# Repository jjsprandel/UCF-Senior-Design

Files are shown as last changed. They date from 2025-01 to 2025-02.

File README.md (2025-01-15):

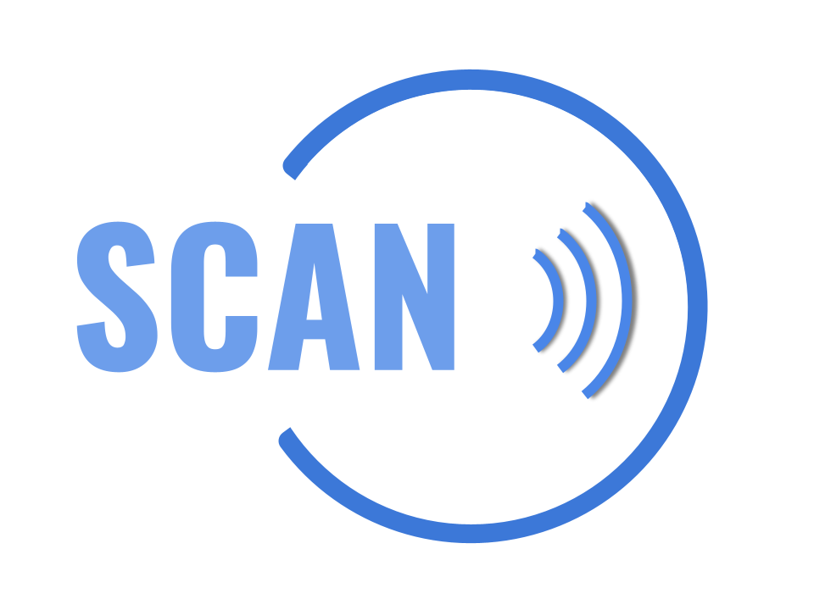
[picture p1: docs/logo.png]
Project Logo
# 

Welcome to the **SCAN** repository! Below, you will find all the necessary information, from hardware design to software documentation.

---

## GitHub Workflows Status 🔧

Here are the current statuses of our GitHub workflows:

| Workflow Name | Status |
| --- | --- |
| **CI - Build** |  |
| **Docker - Test Build** |  |

- **CI - Build**: Ensures the project builds successfully.
- **CI - Tests**: Runs all unit and integration tests to ensure everything is working as expected.
- **Docker - Test Build**: Attempts Docker Build upon changes to the Dockerfile.

---

## Table of Contents 📚
- [💡 Overview](#overview)
- [🔧 Hardware Design](#hardware-design)
- [💻 Software](#software)
- [🔨 Build Instructions](#build-instructions)
- [📑 Documentation](#documentation)
- [⚙️ License](#license)

---

## 💡 Overview
 **SCAN** is a low-cost, IoT-driven kiosk system designed to provide real-time analytics based on check-in and check-out information. By integrating NFC-based authentication, real-time data processing, and a user-friendly interface, SCAN provides users with a near-effortless check-in experience and provides facilities with actionable insights for improving operations. SCAN is able to track attendance and provide detailed analytics on occupancy trends, peak usage hours, and visit durations. These insights are accessible to administrator and facility managers via SCAN’s web application, which can provide them with the necessary statistics to allocate resources efficiently, optimize staffing, and improve user experiences.

---

## 🔧 Hardware Design
<details>
  <summary><strong>📡 Schematic</strong></summary>

  Below is the schematic of the hardware design:

  Schematic
  
  **Key Features**:
  - Feature 1
  - Feature 2
  - Feature 3

  Additional hardware files can be found in the [hardware directory](hardware_design).

</details>

<details>
  <summary><strong>🔌 PCB Design</strong></summary>

  Here's the PCB design layout:

  PCB

  **Important Notes**:
  - Note about the PCB.
  - Power considerations.
  - Any important design choices.

</details>

---

## 💻 Software
<details>
  <summary><strong>💾 Firmware Overview</strong></summary>

  The firmware is designed to work with the hardware for controlling the device. You can find the code [here](path/to/firmware).

  **Key Libraries Used**:
  - Library 1
  - Library 2

</details>

<details>
  <summary><strong>📦 Installation Guide</strong></summary>

  Follow these steps to install the firmware:
  
  1. Step 1
  2. Step 2
  3. Step 3

  Detailed instructions are available in the [installation guide](link_to_guide).

</details>

---

## 🔨 Build Instructions

<details>
  <summary><strong>🛠️ Build Setup</strong></summary>

  To build the project, follow these steps:

  1. Clone the repository:
     ```bash
     git clone https://github.com/jjsprandel/SCAN.git
     ```
  2. Connect your ESP32 to your computer using USB-C. The Docker container is designed to automatically recognize the device and use port 4000 to communicate to the ESP32 for flashing.
  3. Reopen Visual Studio Code in Container. This step requires having the Docker VS Code extension installed on your host machine. 
  4. Within the container, on first run, configure the ESP-IDF extension from the list of commands that come with the ESP-IDF extension.
     4a. Select "Use existing setup."
     4b. The extension should automatically find the right tool paths and folders. Select the configuration option with the auto-filled paths.
  5. Compile the firmware:
     ```bash
     idf.py build
     ```  
      5a. Alternatively, click the wrench button at the bottom of VS Code to build.
  6. Flash the firmware:
     ```bash
     idf.py --port 'rfc2217://host.docker.internal:4000?ign_set_control' flash
     ```
      6a. Alternatively, click the lightning button at the bottom of VS Code to flash.

  **Tips**:
  - Ensure your system meets the requirements listed in the [build prerequisites](link_to_prerequisites).
  - If you encounter issues, check the [troubleshooting guide](link_to_troubleshooting).

</details>

---

## 📑 Documentation
<details>
  <summary><strong>📝 API Documentation</strong></summary>

  - **[API Reference](link_to_api_reference)**: Detailed API usage and function descriptions.
  - **[Hardware Docs](link_to_hardware_docs)**: Documentation on hardware design.

</details>

<details>
  <summary><strong>📚 Additional Resources</strong></summary>

  - **[Project Wiki](link_to_wiki)**: Explore the project wiki for more in-depth articles.
  - **[User Manual](link_to_user_manual)**: Comprehensive user guide for operation.

</details>

---

## 🔌 Dependencies

This project has the following dependencies that need to be installed:

### **Hardware Dependencies:**
- **KiCad Version**: 8.0.6 (required for schematic and PCB design)
  - Download from [KiCad official website](https://kicad.org/download/).
  
### **Software Dependencies:**
- **USB Drivers**: For proper communication with the hardware, ensure that the appropriate USB drivers are installed.
  - For Windows, you can download and install the **[CP210x USB to UART Bridge VCP drivers](https://www.silabs.com/developer-tools/usb-to-uart-bridge-vcp-drivers?tab=downloads)**.
  - For Linux, you should have the necessary drivers already built into the kernel, but check the [driver documentation](https://www.silabs.com/community/interface/usb-bridges) for troubleshooting.

- **Docker Desktop**: Required to run the ESP-IDF containerized environment.
  - Download from **[Docker Desktop website](https://www.docker.com/products/docker-desktop)**.
  - Follow the installation instructions for your operating system.
  
### **Development Tools:**
- **[Visual Studio Code](https://code.visualstudio.com/)**: Recommended IDE for editing the firmware code.

- **[Git](https://git-scm.com/)**: Version control system.

---

## ⚙️ License
SCAN © 2025 is licensed under Creative Commons Attribution-NonCommercial-NoDerivatives 4.0 International. To view a copy of this license, visit https://creativecommons.org/licenses/by-nc-nd/4.0/ or see the [LICENSE](LICENSE) file.

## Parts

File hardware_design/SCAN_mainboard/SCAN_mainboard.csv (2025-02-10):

Reference | Value | Datasheet | Footprint | Qty | DNP
BZ1 | Buzzer | ~ | Connector_PinHeader_2.54mm:PinHeader_1x02_P2.54mm_Vertical | 1
C1,C9,C10,C24,C25,C26,C27,C28,C29,C30,C31,C32,C35,C53,C54,C55,C63,C65 | 10u | ~ | -- mixed values -- | 18
C2,C11,C12,C15,C21,C22,C44,C45,C59 | 0.1u | ~ | -- mixed values -- | 9
C3,C43,C46,C50,C51,C52,C58 | 1u | ~ | -- mixed values -- | 7
C4 | 0.1uF | ~ |  | 1
C5,C6 | 1u | ~ | Capacitor_SMD:C_0805_2012Metric | 2 | DNP
C8,C33,C34,C36,C37 | 10u | ~ | -- mixed values -- | 5 | DNP
C13,C14 | 1nF | ~ | Capacitor_SMD:C_0402_1005Metric | 2
C16,C17 | 0.01u | ~ | Capacitor_SMD:C_0402_1005Metric | 2 | DNP
C18 | 4.7u | ~ | Capacitor_SMD:C_0603_1608Metric | 1
C19 | 47n | ~ | Capacitor_SMD:C_0402_1005Metric | 1
C20,C41 | 47nF | ~ | Capacitor_SMD:C_0402_1005Metric | 2
C23 | 0.1u | ~ | Capacitor_SMD:C_0402_1005Metric | 1 | DNP
C38,C40 | 33u | ~ | Capacitor_Tantalum_SMD:CP_EIA-7343-31_Kemet-D | 2
C39 | 33u | ~ | Capacitor_Tantalum_SMD:CP_EIA-7343-31_Kemet-D | 1 | DNP
C42 | ~ | ~ |  | 1 | DNP
C47,C48 | 390p | ~ | Capacitor_SMD:C_0603_1608Metric | 2
C49 | 3.3u | ~ | Capacitor_SMD:C_1210_3225Metric | 1
C56,C57,C60,C61 | 0.47u | ~ | Capacitor_SMD:C_0603_1608Metric | 4
C62,C64,C66 | 47u | ~ | Capacitor_SMD:C_1210_3225Metric | 3
C67 | 10p | ~ | Capacitor_SMD:C_0603_1608Metric | 1
C68 | 100n | ~ | Capacitor_SMD:C_0402_1005Metric | 1
D1,D2,D3,D4 | ESD441 |  | SCAN_footprints:X2SON2_DPL_TEX | 4
D5,D6,D7 | WS2812B | https://cdn-shop.adafruit.com/datasheets/WS2812B.pdf | LED_SMD:LED_WS2812B_PLCC4_5.0x5.0mm_P3.2mm | 3
D8,D14 | 1N4148W | https://www.vishay.com/docs/85748/1n4148w.pdf | Diode_SMD:D_SOD-123 | 2
D11,D12 | 12V | ~ | Diode_SMD:D_SOD-523 | 2
D13 | LED | ~ | LED_SMD:LED_0805_2012Metric | 1
D15 | NZH10C-115 | https://assets.nexperia.com/documents/data-sheet/NZH_SER.pdf | SCAN_footprints:SODFL3516X120N | 1
D16 | RED | ~ | LED_SMD:LED_0603_1608Metric | 1
J1 | USB_C_16P_Connector | https://www.usb.org/sites/default/files/documents/usb_type-c.zip | SCAN_footprints:USB4110-GF-A_GCT | 1
J2 | Batt_Connector | ~ | SCAN_footprints:TE_282856-2 | 1
J3 | PV_Panel_Connector | ~ | SCAN_footprints:TE_282856-2 | 1
J4 | PIR_CONNECTOR | ~ | Connector_PinHeader_2.54mm:PinHeader_1x03_P2.54mm_Vertical | 1
J5 | Debug_Breakout | ~ |  | 1
J6 | Power_Breakout | ~ |  | 1
J7 | Conn_01x08 | ~ | Connector_PinHeader_2.54mm:PinHeader_1x08_P2.54mm_Vertical | 1
J8 | Conn_01x12 | ~ | SCAN_footprints:12-pin-0.7mm-FPC-Pad | 1
J9 | Keypad | ~ |  | 1
L1 | 1.0u | ~ | SCAN_footprints:SPM6530 | 1
L2 | 2.2u | ~ | SCAN_footprints:IND_IHLP-3232DZ_VIS | 1
Q2,Q3,Q4,Q5 | CSD17581Q3A | https://www.ti.com/lit/ds/symlink/csd17581q3a.pdf | Package_SON:VSON-8_3.3x3.3mm_P0.65mm_NexFET | 4
Q6 | CSD17575Q3 | https://www.ti.com/lit/ds/symlink/csd17577q3a.pdf | Package_SON:VSON-8_3.3x3.3mm_P0.65mm_NexFET | 1
Q7 | BC847BDW1 | http://www.onsemi.com/pub_link/Collateral/BC846BDW1T1-D.PDF | Package_TO_SOT_SMD:SOT-363_SC-70-6 | 1
Q8 | IRF9358TRPBF | https://www.diodes.com//assets/Datasheets/ds31420.pdf | SCAN_footprints:SO8_IRF9358TRPBF_INF | 1
Q9 | BSL308PE | BSL308PEH6327XTSA1 | SCAN_footprints:PG-TSOP6-6-4_INF | 1
Q10 | NTR4503NT1G |  | SCAN_footprints:SOT23_318-08_ONS | 1
R1,R2,R27 | 2.2k | ~ | -- mixed values -- | 3
R3,R4,R5,R10,R14,R17,R34,R37,R49 | 10k | ~ | -- mixed values -- | 9
R15,R16,R29,R30,R31,R67 | 0.01 | ~ | Resistor_SMD:R_2010_5025Metric | 6
R18,R19 | 100k | ~ | Resistor_SMD:R_0402_1005Metric | 2 | DNP
R20,R21,R56 | 0 | ~ | Resistor_SMD:R_0805_2012Metric | 3 | DNP
R22 | 127k | ~ | Resistor_SMD:R_0603_1608Metric | 1
R23,R57,R63,R64 | 100k | ~ | -- mixed values -- | 4
R24,R25 | 294 | ~ | Resistor_SMD:R_0603_1608Metric | 2
R26 | 6.04k | ~ | Resistor_SMD:R_0603_1608Metric | 1
R28 | 100 | ~ | Resistor_SMD:R_0603_1608Metric | 1
R32 | 5.24k | ~ | Resistor_SMD:R_0402_1005Metric | 1
R33 | 30.1k | ~ | Resistor_SMD:R_0402_1005Metric | 1
R35 | 3.3k | ~ |  | 1
R36,R38,R39,R61,R62 | 0Ω | ~ | -- mixed values -- | 5
R40,R52 | 49.9k | ~ | Resistor_SMD:R_0402_1005Metric | 2
R41,R43,R47 | DNP | ~ | Resistor_SMD:R_0603_1608Metric | 3 | DNP
R42,R44,R48,R51,R53,R58,R59 | 1k | ~ | -- mixed values -- | 7
R45,R46 | 5.1k | ~ | Resistor_SMD:R_0603_1608Metric | 2
R50 | 0 | ~ | Resistor_SMD:R_0402_1005Metric | 1
R54,R55 | 2k | ~ | Resistor_SMD:R_0402_1005Metric | 2
R60 | 0Ω | ~ | Resistor_SMD:R_0805_2012Metric | 1 | DNP
R65 | 43.2k | ~ | Resistor_SMD:R_0603_1608Metric | 1
R66 | 4.99k | ~ | Resistor_SMD:R_0603_1608Metric | 1
TH1 | Thermistor_NTC | ~ | Resistor_THT:R_Radial_Power_L11.0mm_W7.0mm_P5.00mm | 1
TP1,TP2,TP3,TP4,TP6,TP7,TP8,TP9,TP10,TP11,TP12,TP13,TP14,TP15,TP16,TP18,TP19,TP20 | TestPoint | ~ | TestPoint:TestPoint_Pad_2.0x2.0mm | 18
U1 | ESP32-C6-WROOM-1-N8 | https://www.espressif.com/sites/default/files/documentation/esp32-c6-wroom-1_wroom-1u_datasheet_en.pdf | SCAN_footprints:ESP32-C6-WROOM-1-N8 | 1
U2 | PCF8574 | http://www.nxp.com/docs/en/data-sheet/PCF8574_PCF8574A.pdf |  | 1
U4 | BQ25798RQMR | BQ25798RQMR | SCAN_footprints:IC_BQ25798RQMR | 1
U5 | TVS2200DRV | http://www.ti.com/lit/ds/symlink/tvs2200.pdf | Package_SON:WSON-6-1EP_2x2mm_P0.65mm_EP1x1.6mm | 1
U6 | CYPD3177-24LQXQ | https://au.mouser.com/datasheet/2/196/CYPR_S_A0012903526_1-3004964.pdf | SCAN_footprints:QFN50P400X400X60-25N-D | 1
U7 | ESD122 | ESD122DMYR | SCAN_footprints:DMY0003A | 1
U8 | CP2102N-A02-xQFN28 | https://www.silabs.com/documents/public/data-sheets/cp2102n-datasheet.pdf | Package_DFN_QFN:QFN-28-1EP_5x5mm_P0.5mm_EP3.35x3.35mm | 1
U9 | LM62460Q3RPHRQ1 |  | SCAN_footprints:16-VQFN-HR | 1

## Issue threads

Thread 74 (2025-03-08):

NFC problem reading tag with fast movement

jjsprandel, 2025-03-08:
When a user quickly moves their NFC tag into range of the PN532 reader, the software cannot read the data. The current code requires the tag to be moved into range slowly, posing an issue for typical interactions with the kiosk

Closed 2025-04-12.

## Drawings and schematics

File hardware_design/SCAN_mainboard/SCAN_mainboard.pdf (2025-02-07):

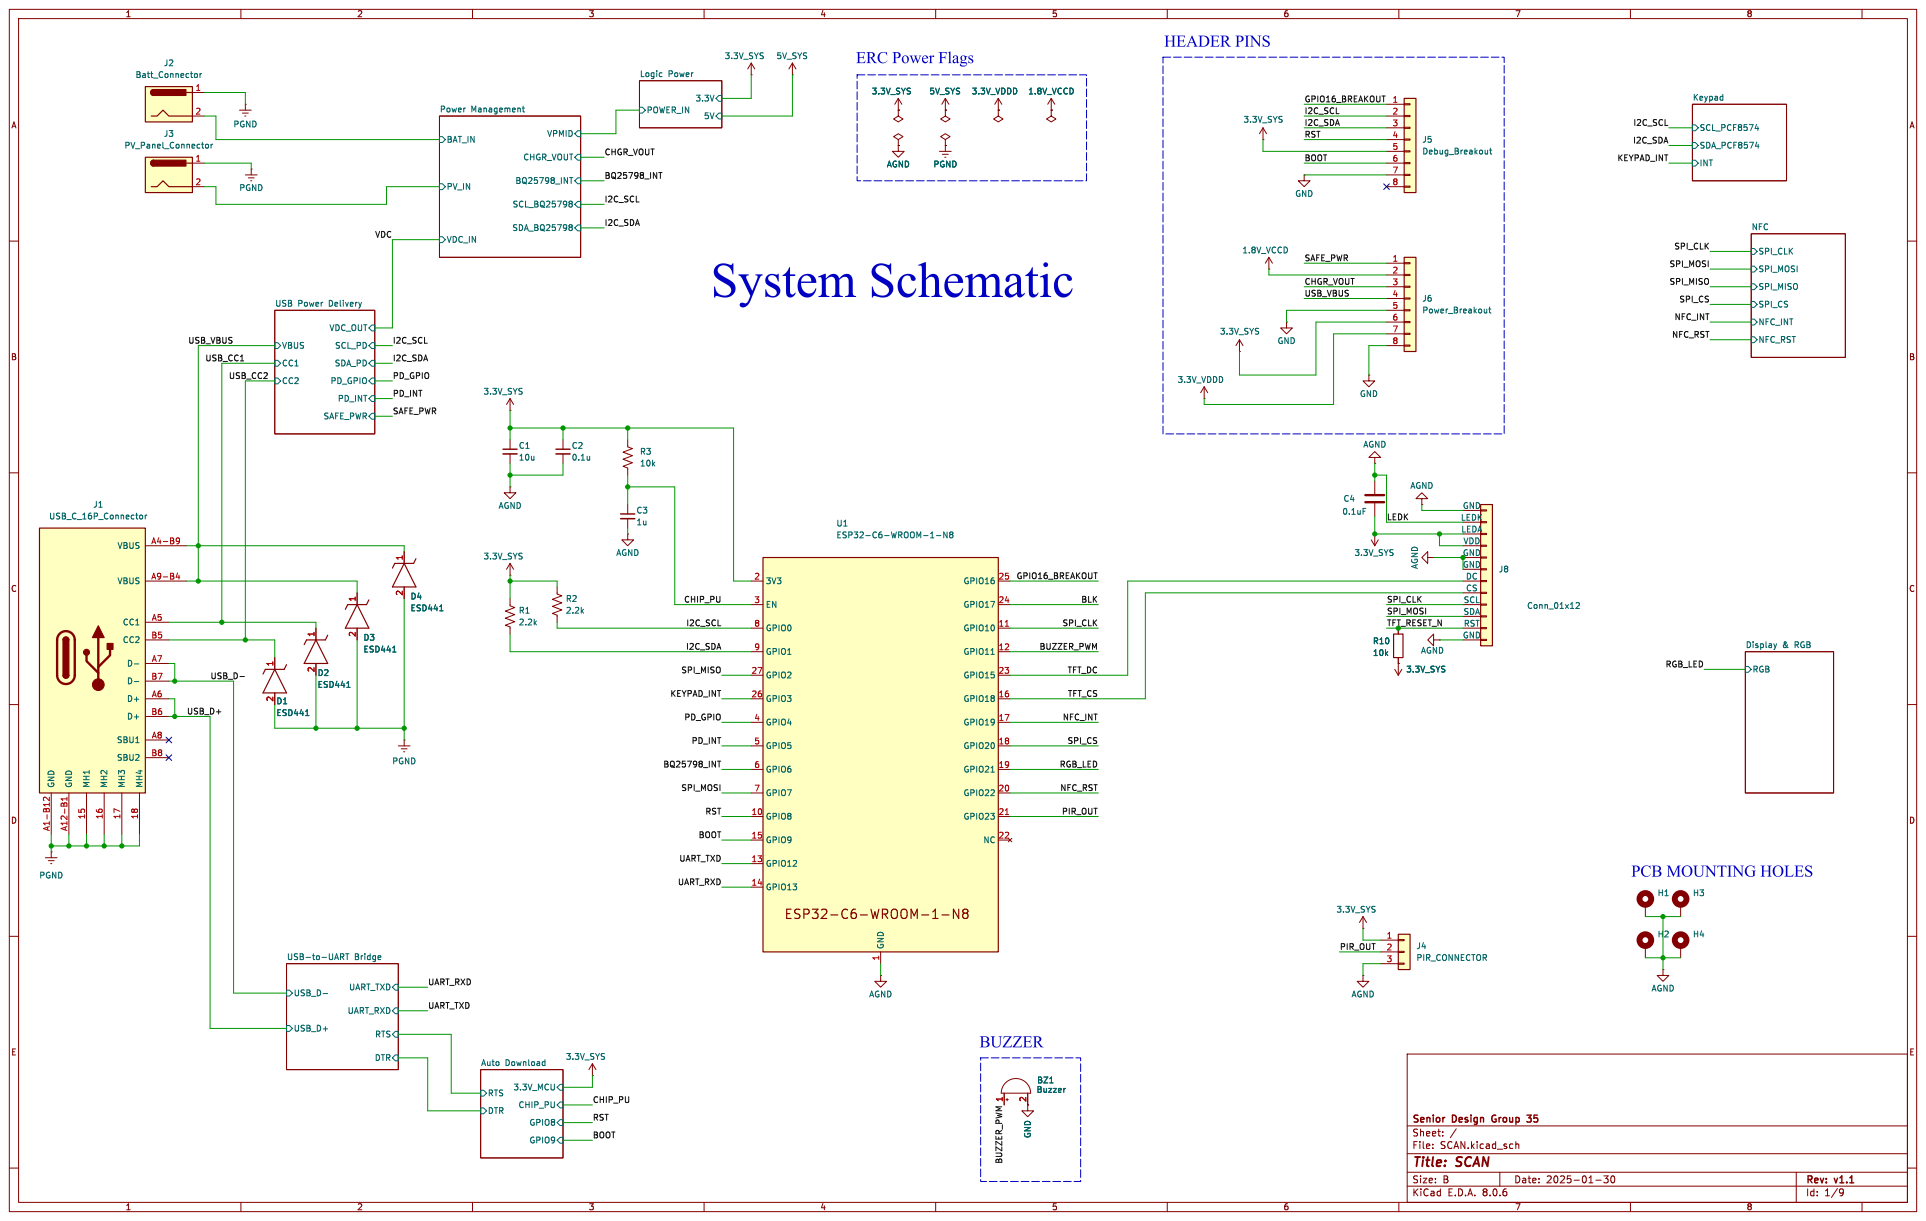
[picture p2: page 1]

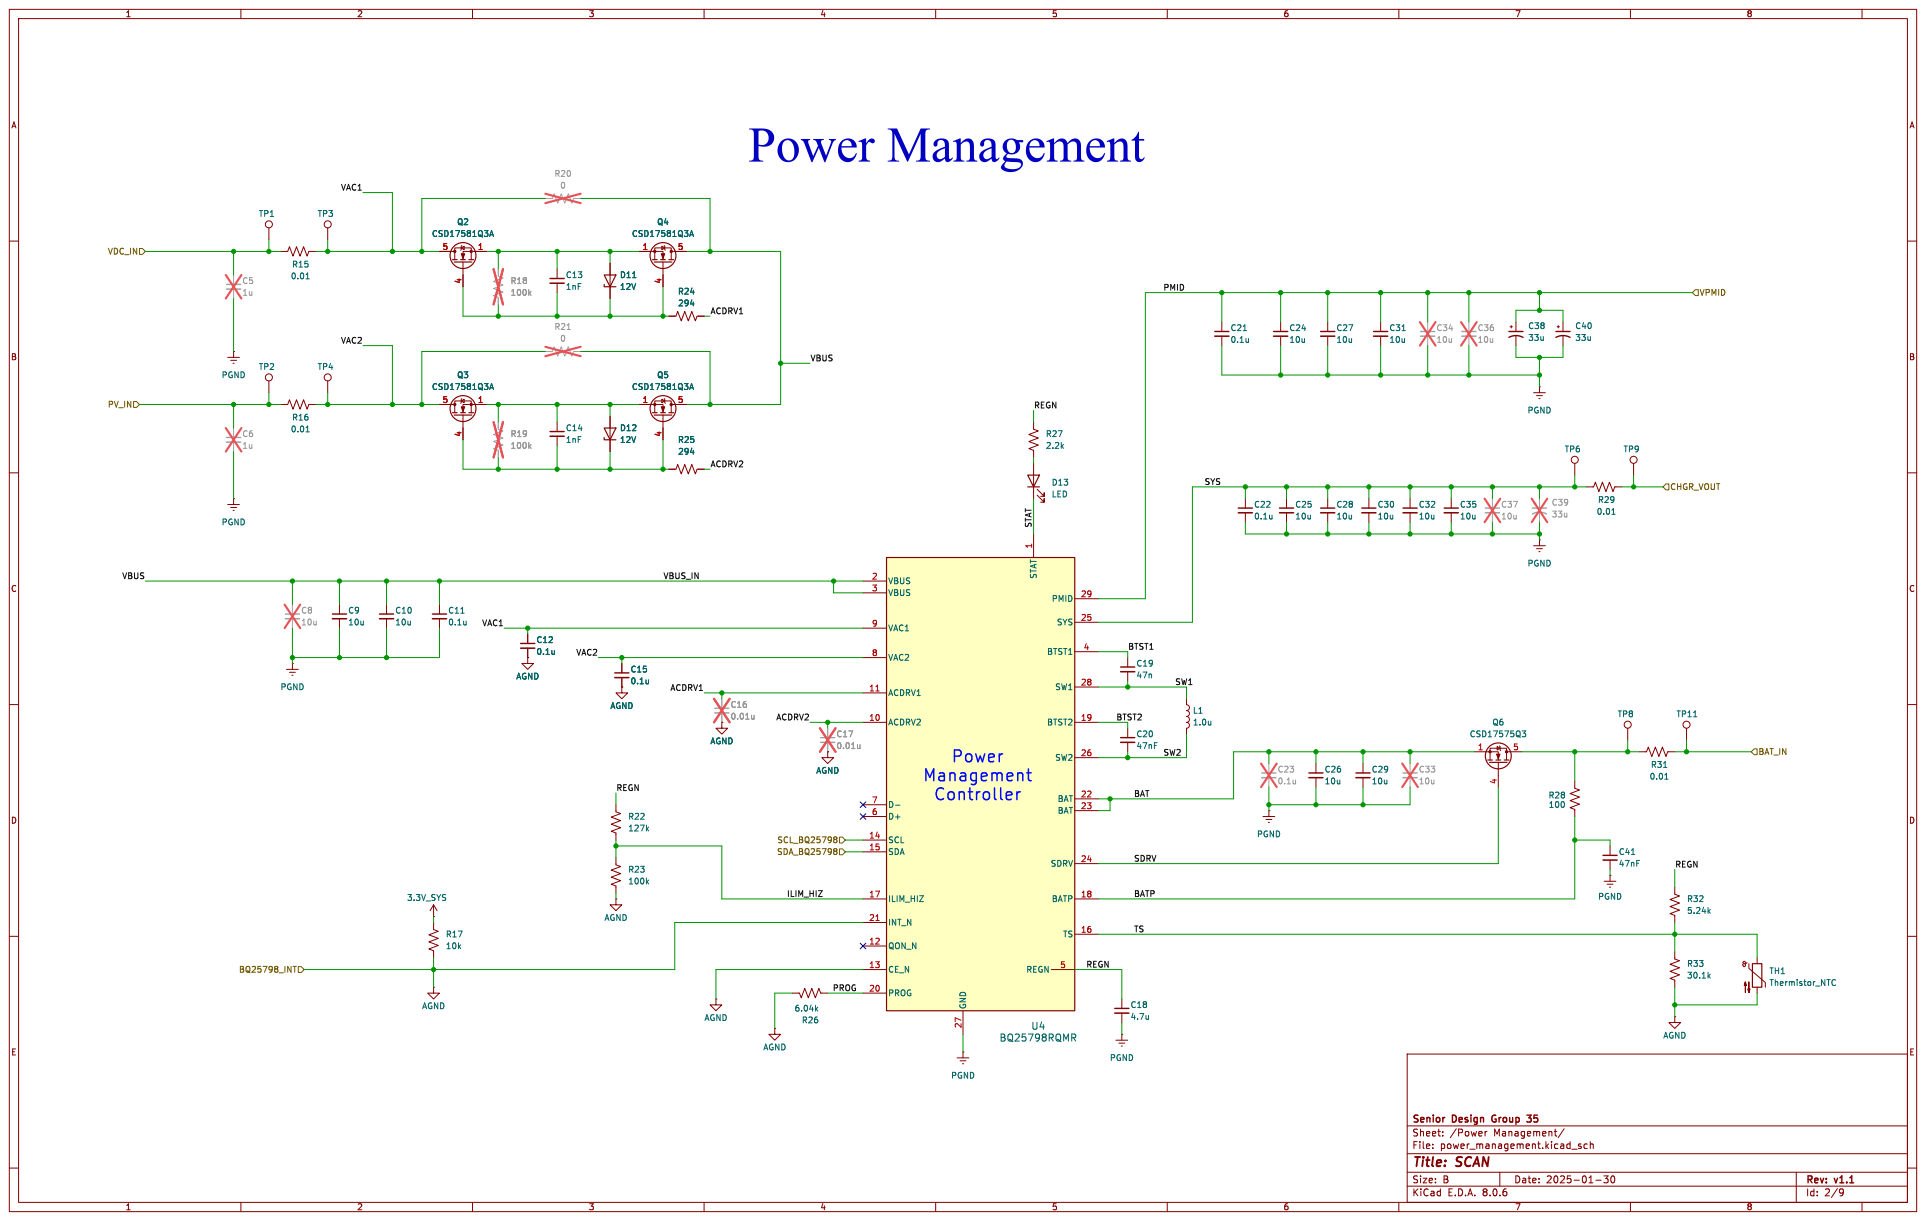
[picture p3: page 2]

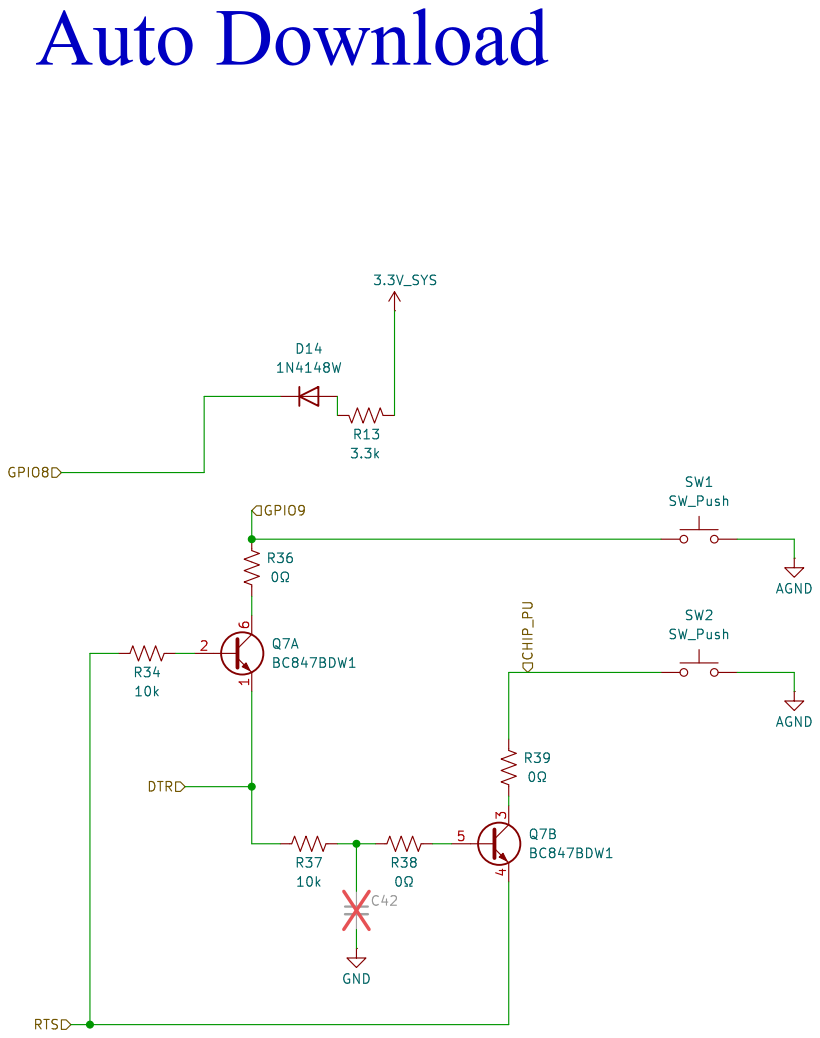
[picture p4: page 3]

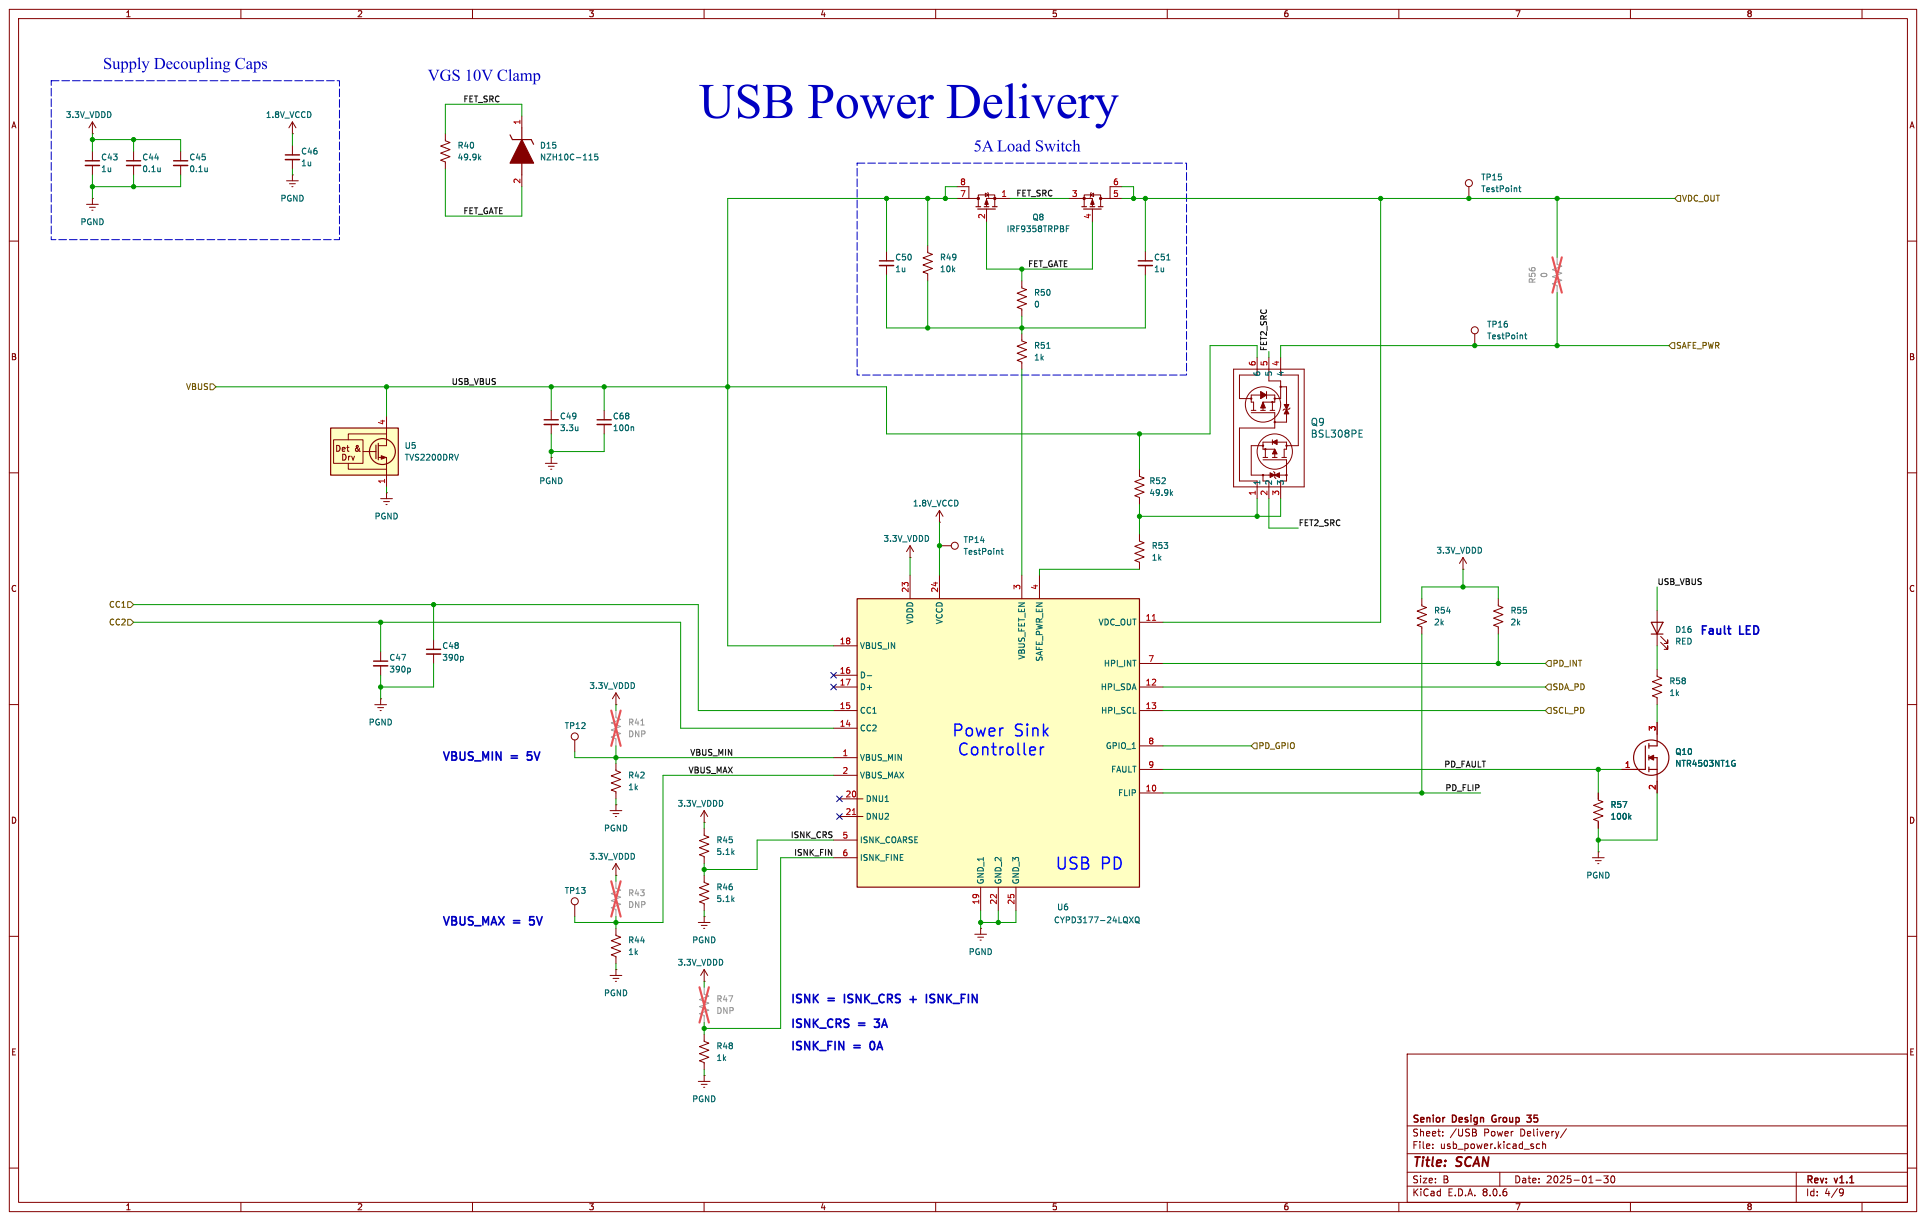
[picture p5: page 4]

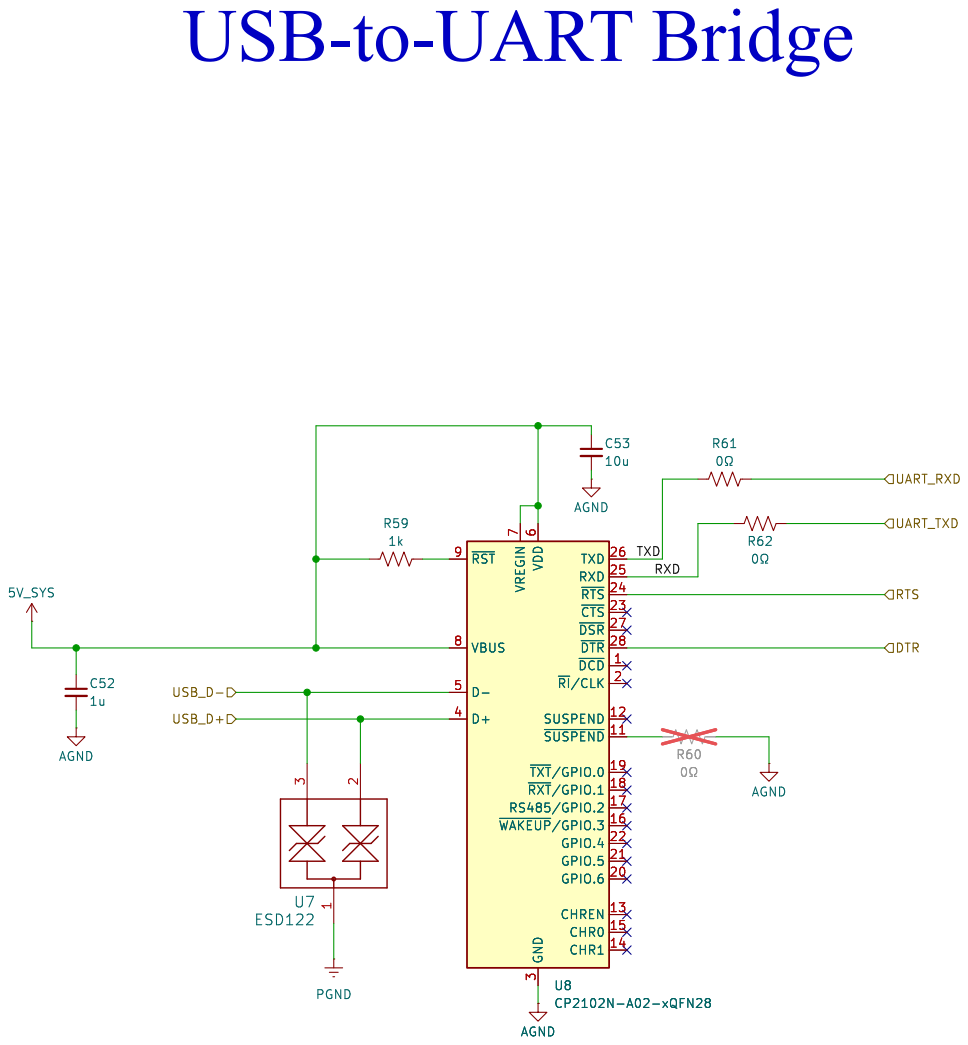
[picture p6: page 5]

TXD USB-to-UARTBridge

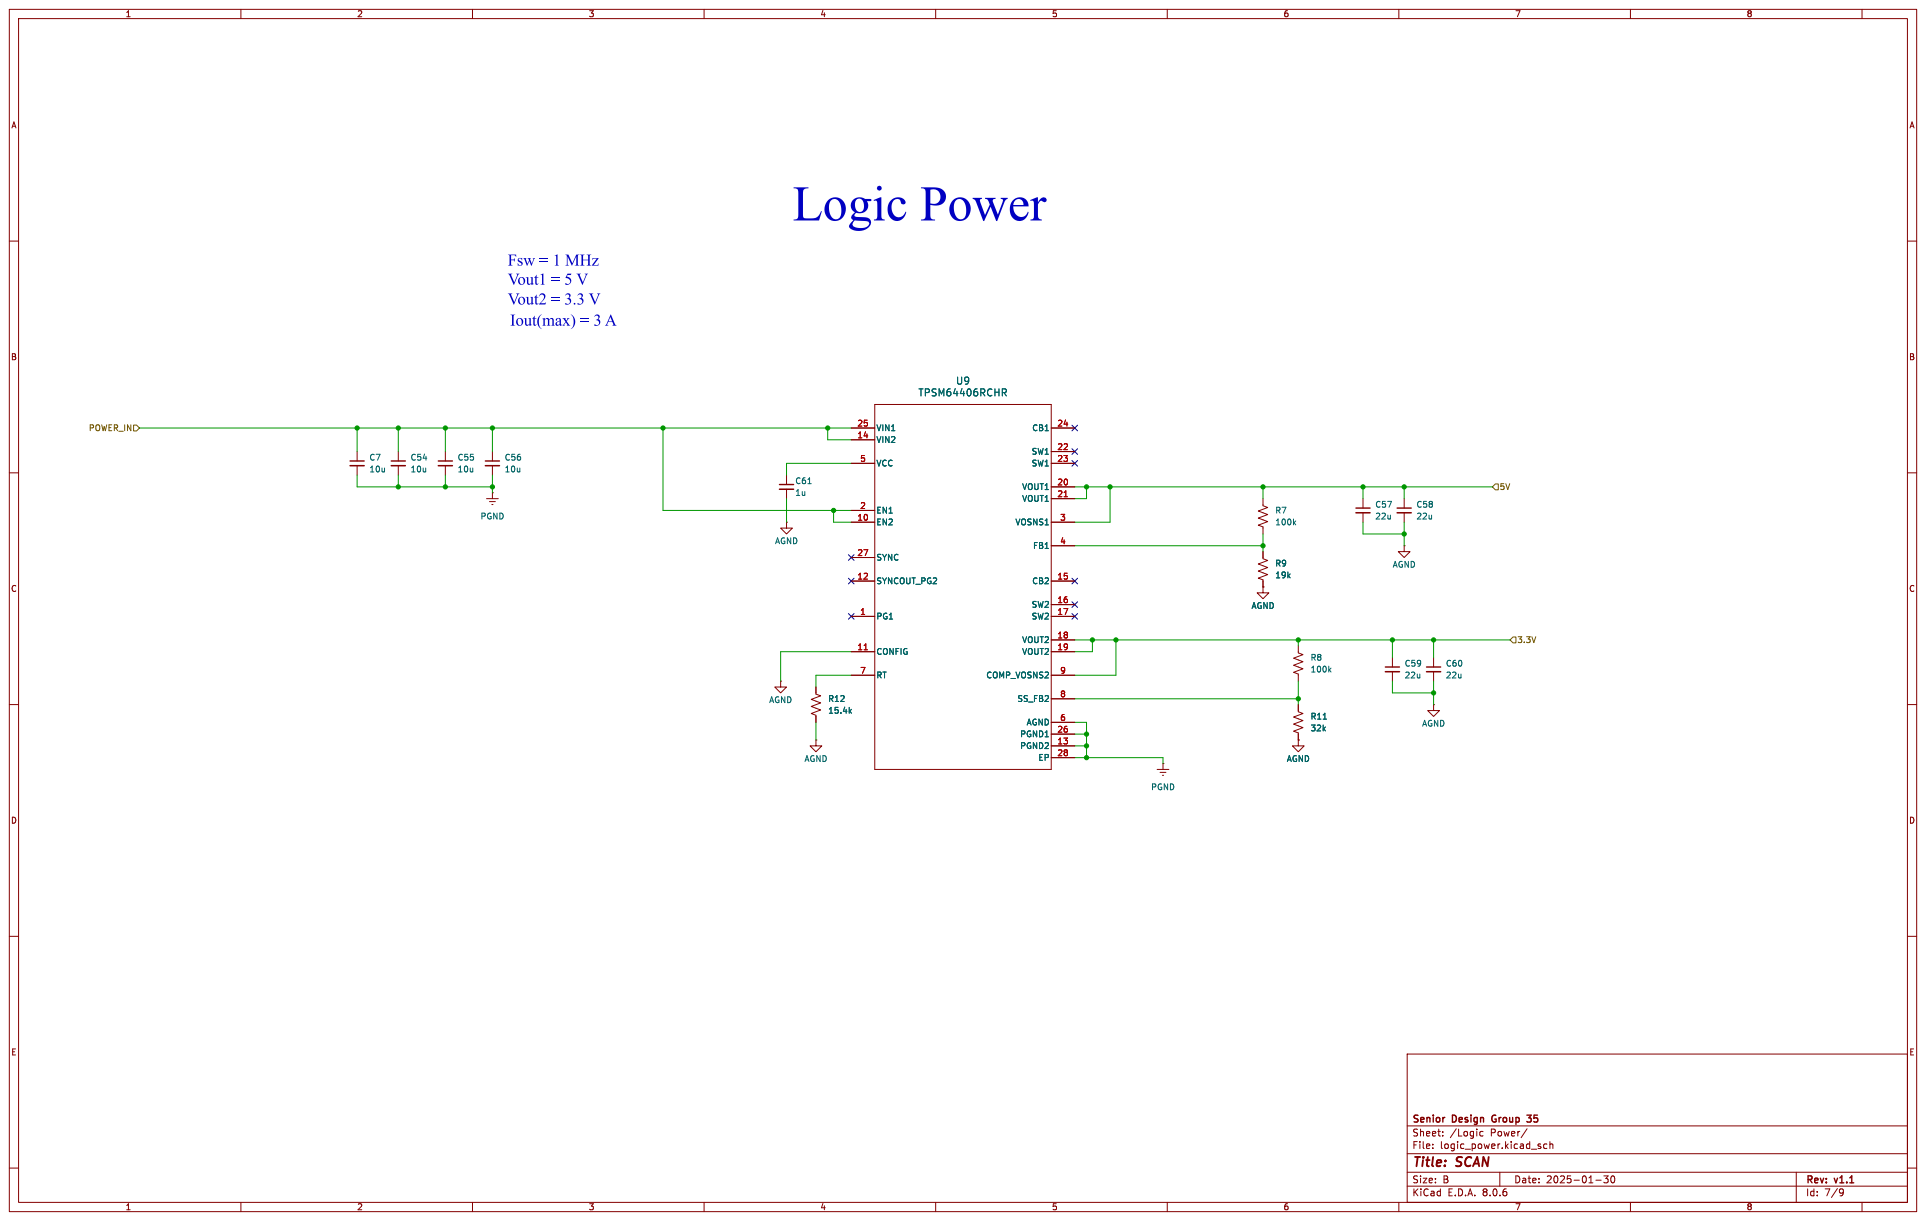
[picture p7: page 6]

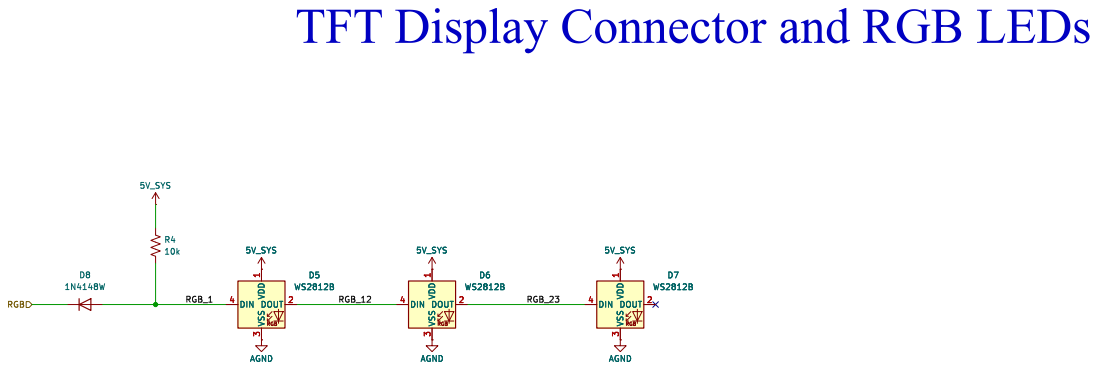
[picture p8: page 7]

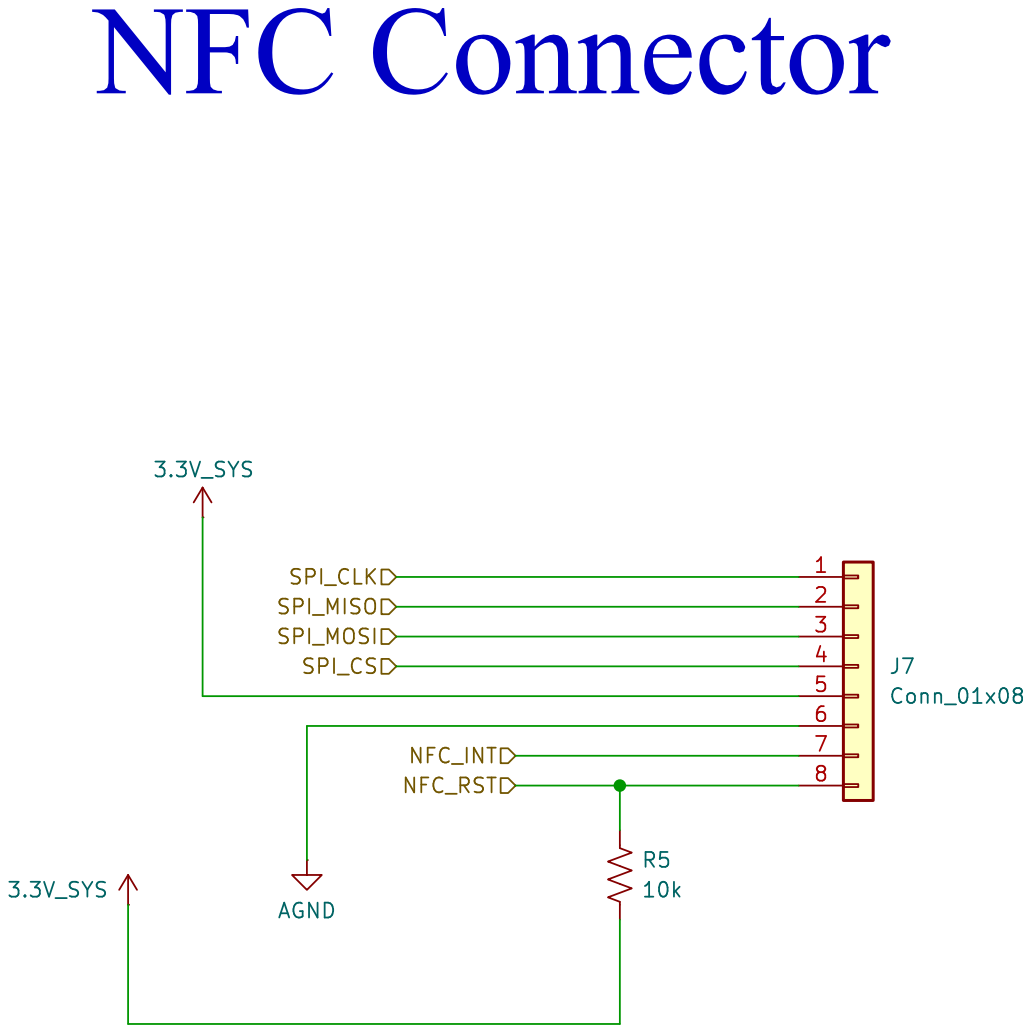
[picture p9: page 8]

Id: 8/9 Title: File: nfc.kicad_sch Sheet: /NFC/

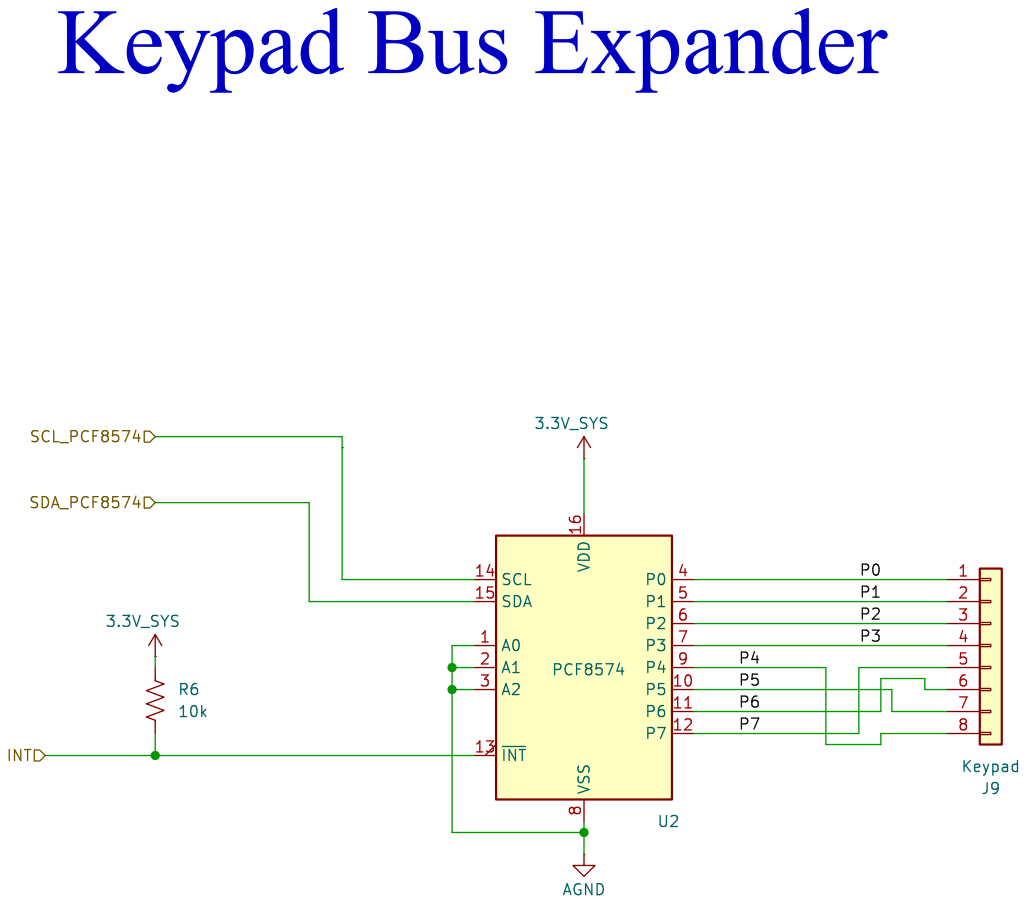
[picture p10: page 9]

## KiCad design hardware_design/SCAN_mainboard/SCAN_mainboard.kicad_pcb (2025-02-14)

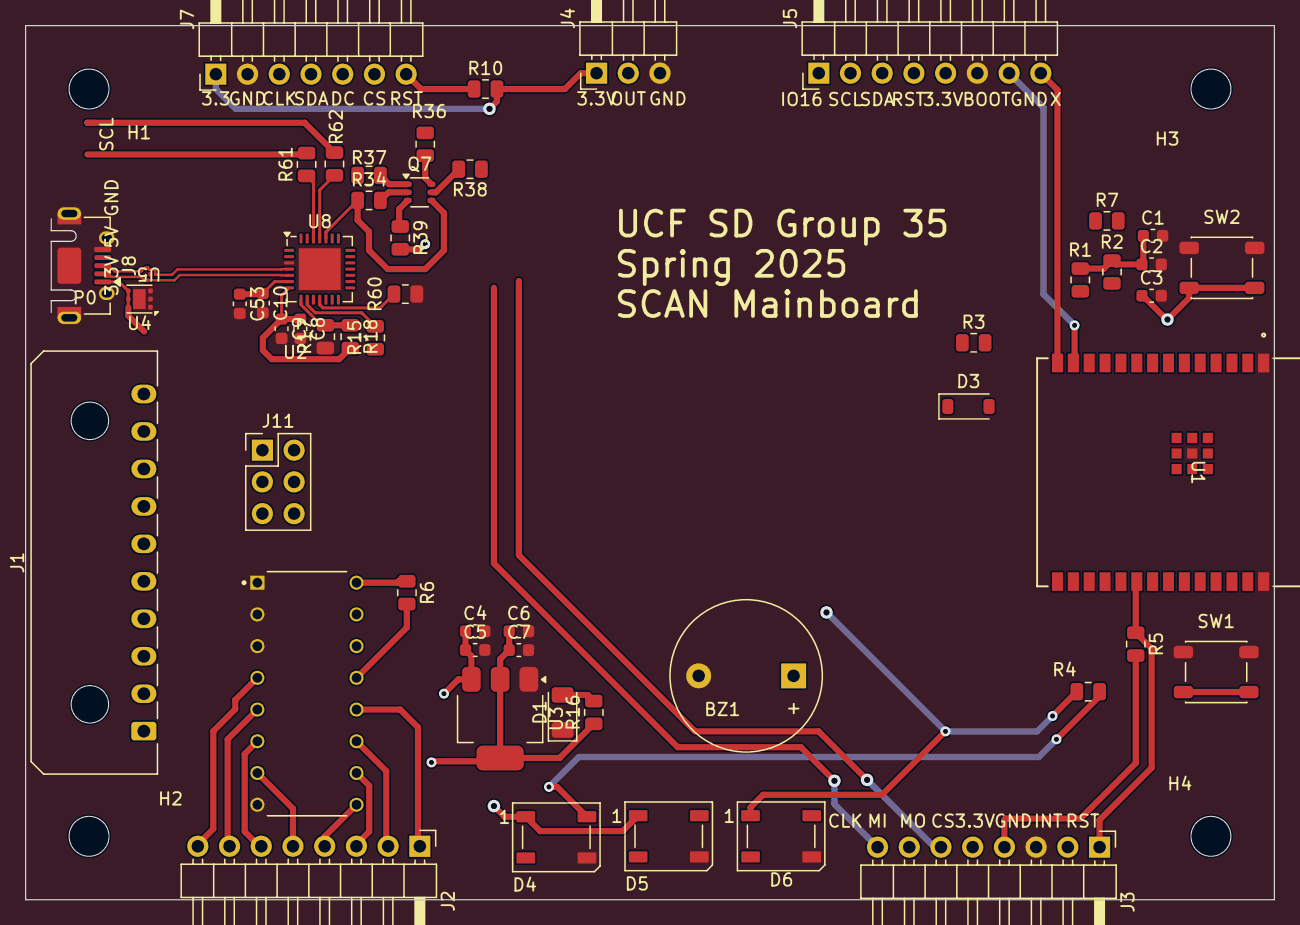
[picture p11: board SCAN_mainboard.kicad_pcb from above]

Board: 2 copper layers, 100.0 x 70.0 mm, 58 parts (0 on the bottom side), 58 nets.

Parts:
BZ1: Buzzer; Buzzer_12x9.5RM7.6
C1: 10u; C_0603_1608Metric
C2: 0.1u; C_0603_1608Metric
C3: 1u; C_0603_1608Metric
C4, C6: 10uF; C_0603_1608Metric
C5, C7: 100nF; C_0603_1608Metric
C8, C53: .1u; C_0603_1608Metric
C9, C10: 4.7u; C_0603_1608Metric
D1: LED; LED_1206_3216Metric
D3: 1N4148W; D_SOD-123
D4: SUCCESS_LED; LED_WS2812B_PLCC4_5.0x5.0mm_P3.2mm
D5: FAILURE_LED; LED_WS2812B_PLCC4_5.0x5.0mm_P3.2mm
D6: ADMIN_LED; LED_WS2812B_PLCC4_5.0x5.0mm_P3.2mm
H1, H2, H3, H4: MountingHole_Pad; MountingHole_3.2mm_M3
J1: Conn_01x10; Molex_Micro-Fit_3.0_43650-1000_1x10_P3.00mm_Horizontal
J2: KEYPAD_CONN; PinHeader_1x08_P2.54mm_Horizontal
J3: PN532_CONN; PinHeader_1x08_P2.54mm_Horizontal
J4: PIR_CONN; PinHeader_1x03_P2.54mm_Horizontal
J5: DEBUG_BREAKOUT; PinHeader_1x08_P2.54mm_Horizontal
J7: TFT_CONN; PinHeader_1x07_P2.54mm_Horizontal
J8: USB_B_Micro; USB_Micro-AB_Molex_47590-0001
J11: PWR_MUX; PinHeader_2x03_P2.54mm_Vertical
Q7: BC847BDW1; SOT-363_SC-70-6
R1, R2: 2.2k; R_0805_2012Metric
R3, R4, R5, R6, R10, R34, R37: 10k; R_0805_2012Metric
R7: 3.3k; R_0805_2012Metric
R15, R16: 1k; R_0805_2012Metric
R17: 47.5k; R_0805_2012Metric
R18: 22.1k; R_0805_2012Metric
R36, R38, R39, R60, R61, R62: 0Ω; R_0805_2012Metric
SW1: RST_SWITCH; SW_SPST_PTS647_Sx38
SW2: SW_Push; SW_SPST_PTS647_Sx38
U1: ESP32-C6-WROOM-1-N8
U2: PCF8574; DIP794W45P254L1969H508Q16
U3: AMS1117-3.3; SOT-223-3_TabPin2
U4: TVS2200DRV; WSON-6-1EP_2x2mm_P0.65mm_EP1x1.6mm
U5: ESD122DMYR; DMY0003A
U8: CP2102N-A02-xQFN28; QFN-28-1EP_5x5mm_P0.5mm_EP3.35x3.35mm

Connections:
3.3V_LDO_OUT: C6.1, C7.1, J11.3, R16.1, U3.2 (VO)
3.3V_PWR_BRD: J1.2, J11.1
3.3V_SYS: C1.1, C2.1, J3.4, J4.1, J5.5, J7.1, J11.2, R1.1, R2.1, R3.1, R5.2, R6.1, R7.2, R10.2, U1.2 (3V3), U2.16 (VDD)
5V_PWR_BRD: J1.1, J11.4
5V_SYS: C4.1, C5.1, C8.1, C9.1, D4.1 (VDD), D5.1 (VDD), D6.1 (VDD), J11.5, R4.1, R18.2, U3.3 (VI), U8.7 (VREGIN)
/Auto Download/DTR: Q7.1 (E1), R37.1, U8.28 (~DTR)
/Auto Download/RTS: Q7.4 (E2), R34.1, U8.24 (~RTS)
/BOOT: J5.1, R36.2, SW1.2, U1.15 (GPIO9)
/BQ25798_INT: J1.6, U1.6 (GPIO6)
/BUZZER_PWM: BZ1.1 (+), U1.12 (GPIO11)
/CHIP_PU: C3.1, R3.2, R39.2, SW2.2, U1.3 (EN)
/GPIO12_BREAKOUT: J5.7, U1.13 (GPIO12)
/GPIO13_BREAKOUT: J5.8, U1.14 (GPIO13)
/I2C_SCL: J1.10, J5.2, R2.2, U1.8 (GPIO0), U2.14 (SCL)
/I2C_SDA: J1.9, J5.3, R1.2, U1.9 (GPIO1), U2.15 (SDA)
/KEYPAD_INT: R6.2, U1.26 (GPIO3), U2.13 (~INT)
/MICRO_USB_D+: J8.3 (D+), U5.2, U8.4 (D+)
/MICRO_USB_D-: J8.2 (D-), U5.3, U8.5 (D-)
/NFC_INT: J3.2, U1.17 (GPIO19)
/NFC_RST: J3.1, R5.1, U1.20 (GPIO22)
/P0: J2.8, U2.4 (P0)
/P1: J2.7, U2.5 (P1)
/P2: J2.6, U2.6 (P2)
/P3: J2.5, U2.7 (P3)
/P4: J2.4, U2.9 (P4)
/P5: J2.3, U2.10 (P5)
/P6: J2.2, U2.11 (P6)
/P7: J2.1, U2.12 (P7)
/PD_GPIO: J1.8, U1.4 (GPIO4)
/PD_INT: J1.7, U1.5 (GPIO5)
/PIR_OUT: J4.2, U1.21 (GPIO23)
/RGB_1: D3.2 (A), D4.4 (DIN), R4.2
/RGB_12: D4.2 (DOUT), D5.4 (DIN)
/RGB_23: D5.2 (DOUT), D6.4 (DIN)
/RGB_CTRL: D3.1 (K), J5.4, R7.1, U1.10 (GPIO8)
/SPI_CLK: J3.8, J7.3, U1.11 (GPIO10)
/SPI_CS: J3.5, U1.18 (GPIO20)
/SPI_MISO: J3.7, U1.27 (GPIO2)
/SPI_MOSI: J3.6, J7.4, U1.7 (GPIO7)
/TFT_CS: J7.6, U1.16 (GPIO18)
/TFT_DC: J7.5, U1.23 (GPIO15)
/TFT_RESET_N: J7.7, R10.1, U1.19 (GPIO21)
/UART_RXD: J1.4, R61.2, U1.24 (GPIO17)
/UART_TXD: J1.5, R62.2, U1.25 (GPIO16)
/USB-to-UART Bridge/RST: R15.2, U8.9 (~RST)
/USB-to-UART Bridge/RXD: R62.1, U8.25 (RXD)
/USB-to-UART Bridge/SUSPEND: R60.1, U8.11 (~SUSPEND)
/USB-to-UART Bridge/TXD: R61.1, U8.26 (TXD)
/USB-to-UART Bridge/VBUS_SNS: R17.2, R18.1, U8.8 (VBUS)
/USB-to-UART Bridge/VDD: C10.1, C53.1, R15.1, U8.6 (VDD)
AGND: BZ1.2 (-), C1.2, C2.2, C3.2, C4.2, C5.2, C6.2, C7.2, C8.2, C9.2, C10.2, C53.2, D1.1 (K), D4.3 (VSS), D5.3 (VSS), D6.3 (VSS), J3.3, J4.3, J5.6, J7.2, J8.5 (GND), J8.6 (Shield), R17.1, R60.2, SW1.1, SW2.1, U1.1 (GND), U1.28 (GND), U1.29 (GND), U2.1 (A0), U2.2 (A1), U2.3 (A2), U2.8 (VSS), U3.1 (GND), U4.1 (GND), U4.2 (GND), U4.3 (GND), U4.7 (GND), U5.1, U8.3 (GND), U8.29 (GND)
unnamed: D1.2 (A), R16.2
unnamed: Q7.2 (B1), R34.2
unnamed: Q7.6 (C1), R36.1
unnamed: Q7.5 (B2), R38.2
unnamed: Q7.3 (C2), R39.1
unnamed: R37.2, R38.1
VBUS: J8.1 (VBUS), J11.6, U4.4 (IN), U4.5 (IN), U4.6 (IN)

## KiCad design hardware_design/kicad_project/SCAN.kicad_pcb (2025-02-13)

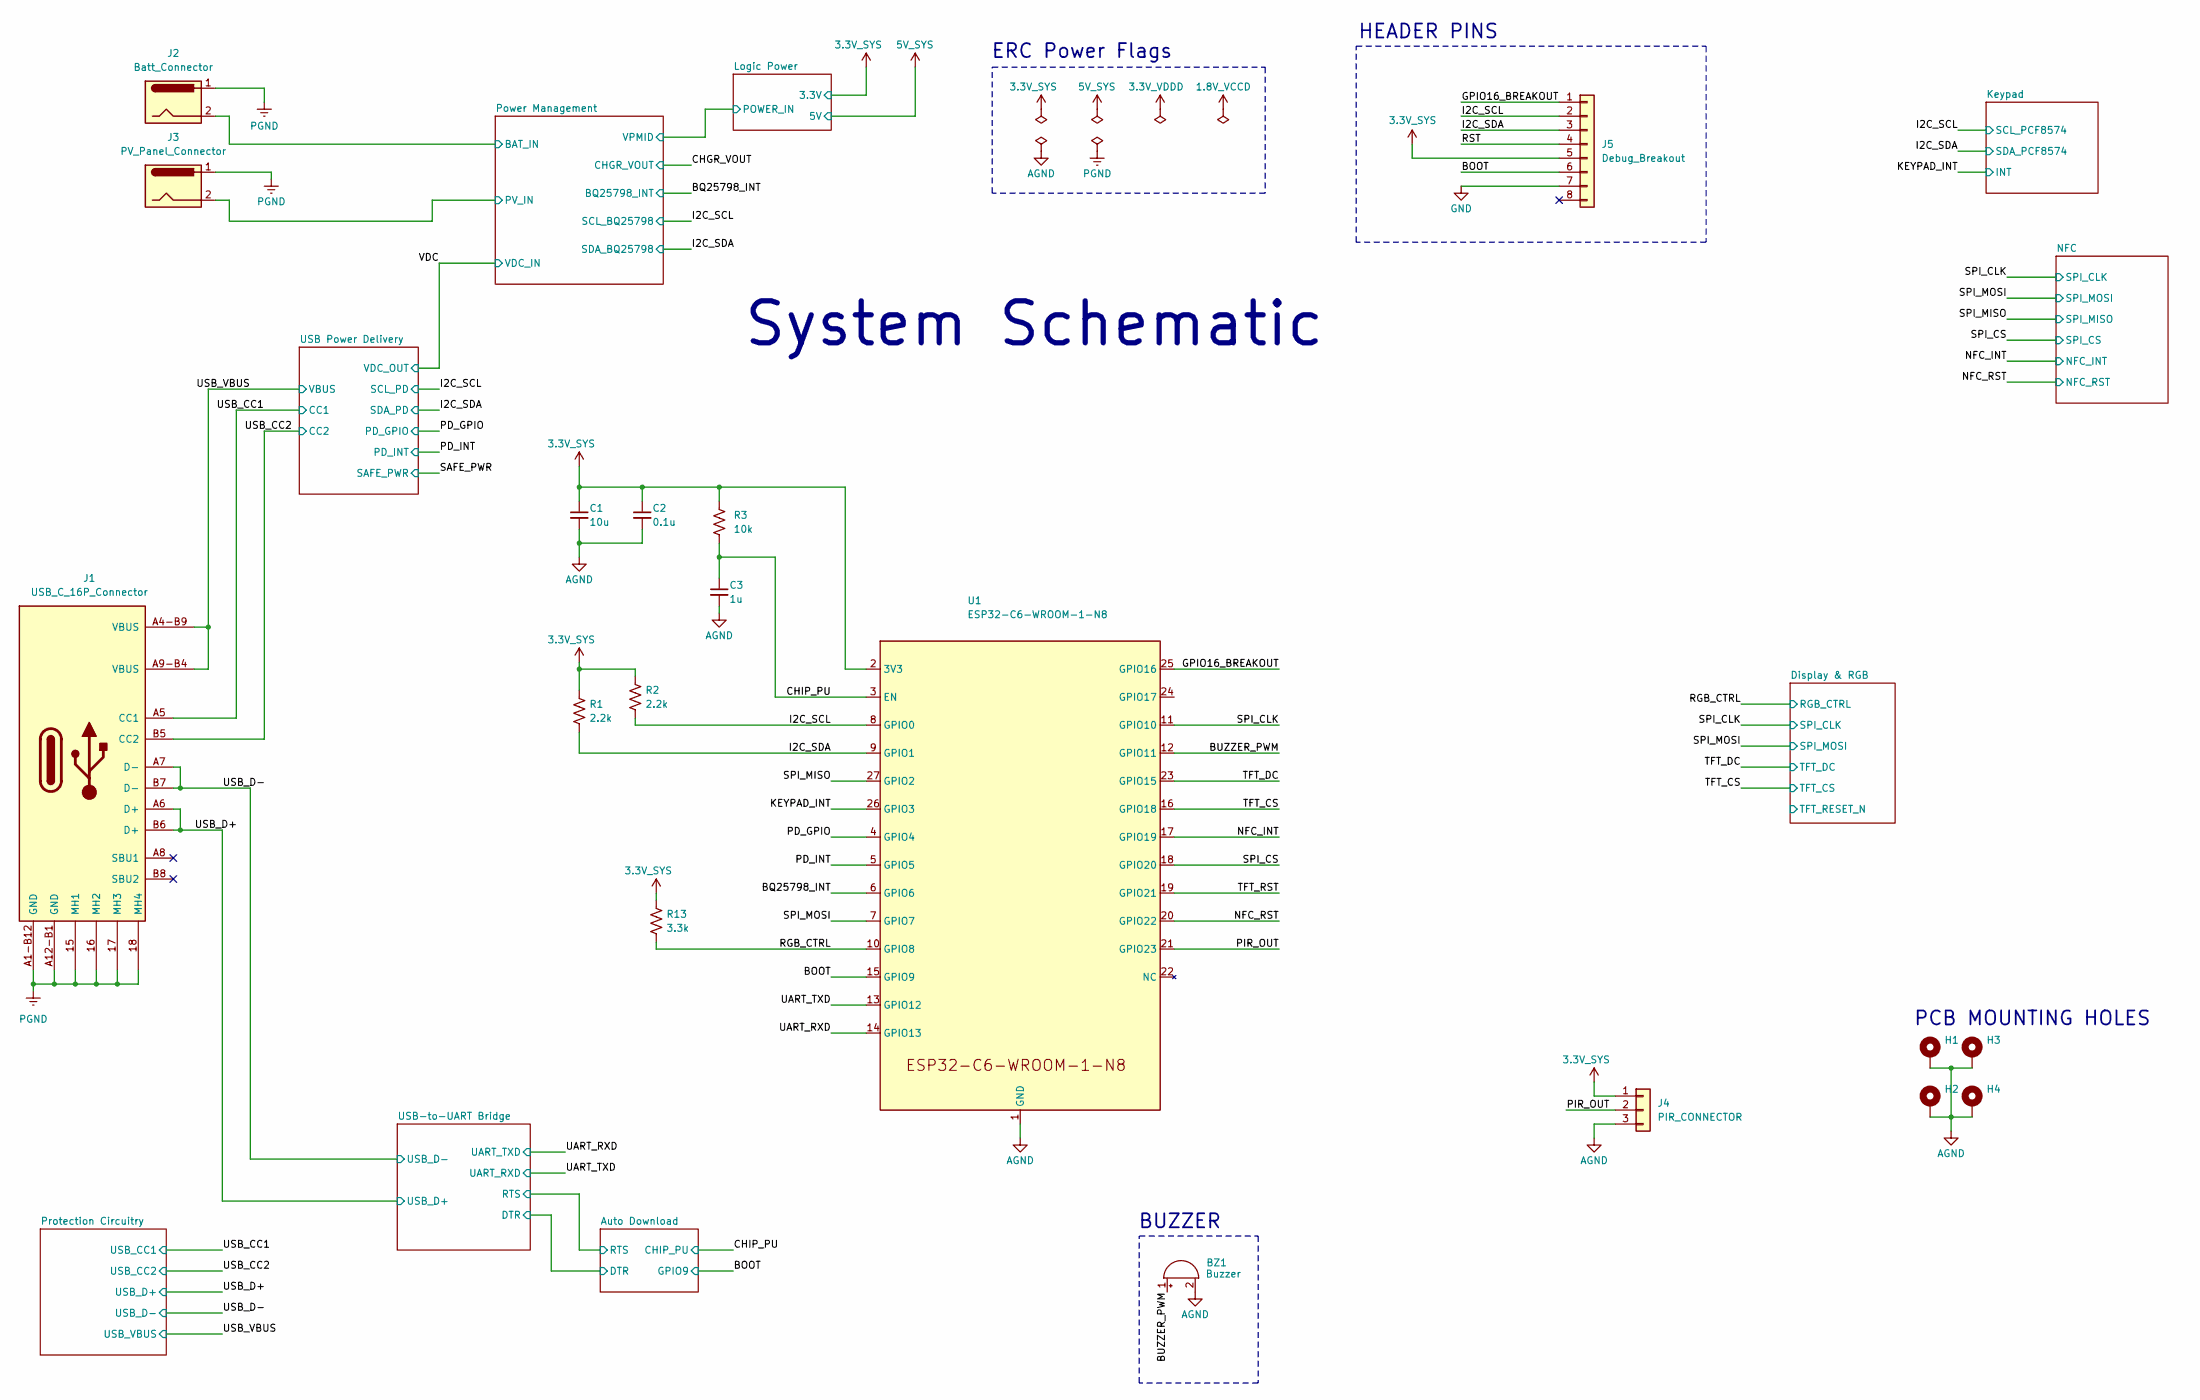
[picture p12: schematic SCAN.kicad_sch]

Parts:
BZ1: Buzzer; PinHeader_1x02_P2.54mm_Vertical
C1: 10u
C2: 0.1u
C3: 1u
H1, H2, H3, H4: MountingHole_Pad; MountingHole_3.2mm_M3
J1: USB_C_16P_Connector; USB4110-GF-A_GCT
J2: Batt_Connector; TE_282856-2
J3: PV_Panel_Connector; TE_282856-2
J4: PIR_CONNECTOR; PinHeader_1x03_P2.54mm_Vertical
J5: Debug_Breakout
R1, R2: 2.2k; R_0805_2012Metric
R3: 10k; R_0805_2012Metric
R13: 3.3k; R_0805_2012Metric
U1: ESP32-C6-WROOM-1-N8

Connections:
/BOOT: J5.6, U1.15 (GPIO9); also elsewhere on the board
/BUZZER_PWM: BZ1.1 (-), U1.12 (GPIO11)
/CHIP_PU: C3.1, R3.2, U1.3 (EN); also elsewhere on the board
/GPIO16_BREAKOUT: J5.1, U1.25 (GPIO16)
/I2C_SCL: J5.2, R2.2, U1.8 (GPIO0); also elsewhere on the board
/I2C_SDA: J5.3, R1.2, U1.9 (GPIO1); also elsewhere on the board
/KEYPAD_INT: U1.26 (GPIO3); also elsewhere on the board
/NFC_INT: U1.17 (GPIO19); also elsewhere on the board
/NFC_RST: U1.20 (GPIO22); also elsewhere on the board
/PD_GPIO: U1.4 (GPIO4); also elsewhere on the board
/PD_INT: U1.5 (GPIO5); also elsewhere on the board
/PIR_OUT: J4.2, U1.21 (GPIO23)
/Power Management/BAT_IN: J2.2; also elsewhere on the board
/Power Management/PV_IN: J3.2; also elsewhere on the board
/SPI_CLK: U1.11 (GPIO10); also elsewhere on the board
/SPI_CS: U1.18 (GPIO20); also elsewhere on the board
/SPI_MISO: U1.27 (GPIO2); also elsewhere on the board
/SPI_MOSI: U1.7 (GPIO7); also elsewhere on the board
/TFT_CS: U1.16 (GPIO18); also elsewhere on the board
/TFT_DC: U1.23 (GPIO15); also elsewhere on the board
/TFT_RST: U1.19 (GPIO21)
/UART_RXD: U1.14 (GPIO13); also elsewhere on the board
/UART_TXD: U1.13 (GPIO12); also elsewhere on the board
/USB_CC1: J1.A5 (CC1); also elsewhere on the board
/USB_CC2: J1.B5 (CC2); also elsewhere on the board
/USB_D+: J1.A6 (D+), J1.B6 (D+); also elsewhere on the board
/USB_D-: J1.A7 (D-), J1.B7 (D-); also elsewhere on the board
/USB_VBUS: J1.A4-B9 (VBUS), J1.A9-B4 (VBUS); also elsewhere on the board
AGND: BZ1.2 (+), C1.2, C2.2, C3.2, H1.1, H2.1, H3.1, H4.1, J4.3, U1.1 (GND), U1.6 (GPIO6); also elsewhere on the board
PGND: J1.15 (MH1), J1.16 (MH2), J1.17 (MH3), J1.18 (MH4), J1.A1-B12 (GND), J1.A12-B1 (GND), J2.1, J3.1; also elsewhere on the board

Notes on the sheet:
HEADER PINS
System Schematic
BUZZER
ERC Power Flags
PCB MOUNTING HOLES

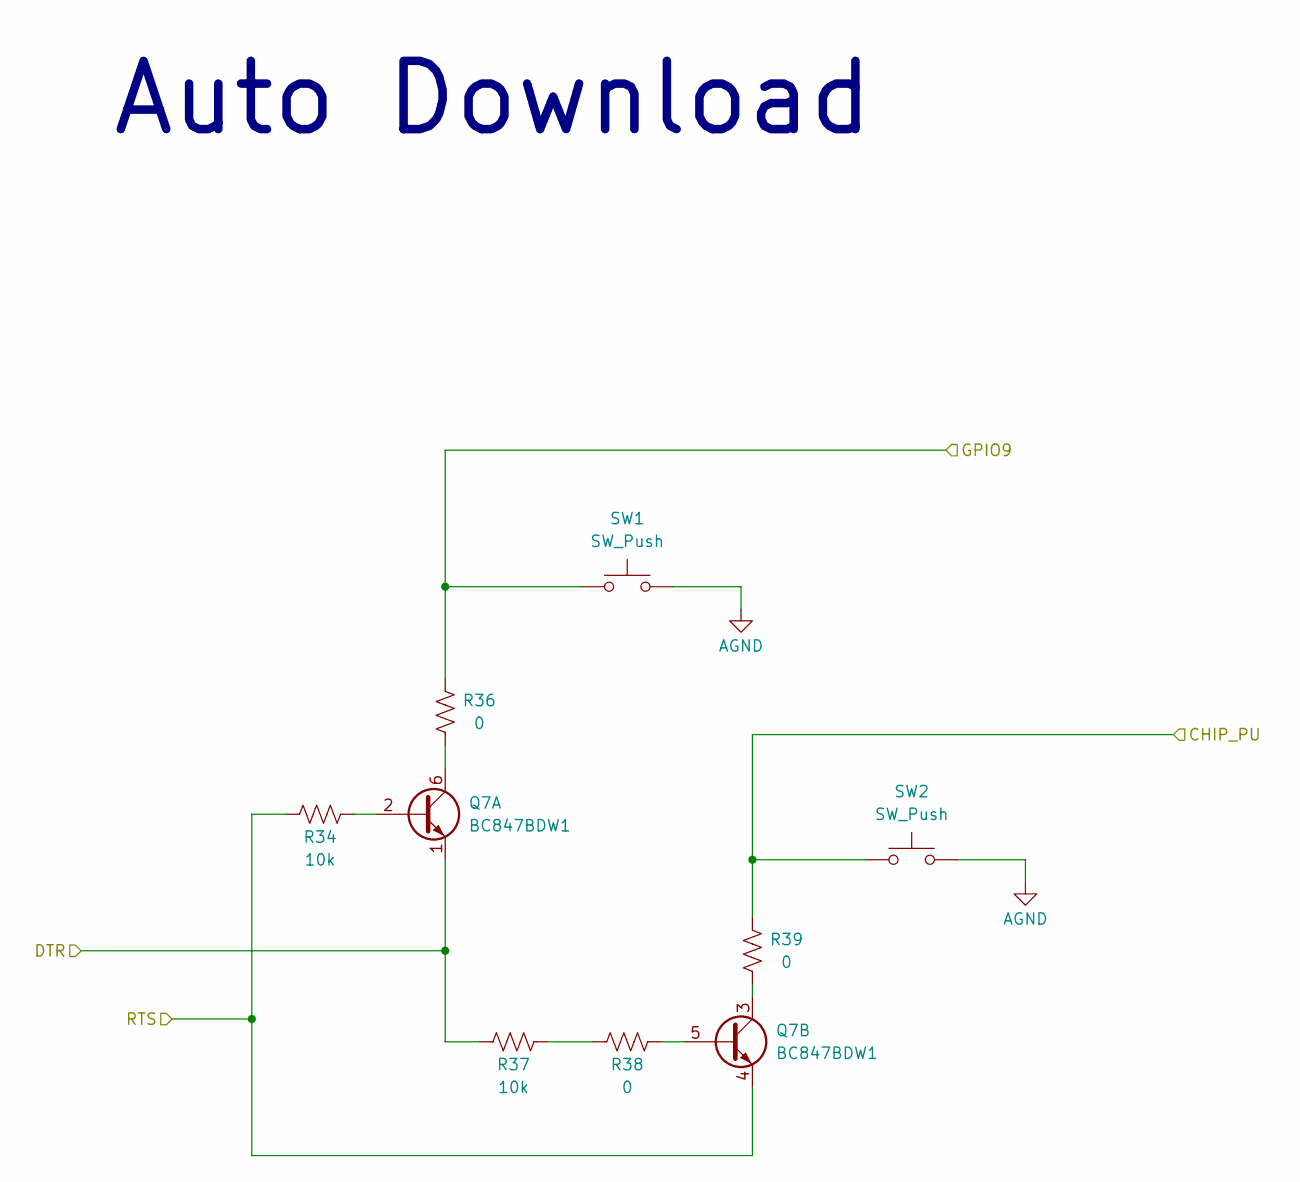
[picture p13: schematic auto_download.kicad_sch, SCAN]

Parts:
Q7: BC847BDW1; SOT-363_SC-70-6
R34, R37: 10k; R_0805_2012Metric
R36, R38, R39: 0; R_0805_2012Metric
SW1, SW2: SW_Push; SW_SPST_PTS647_Sx38

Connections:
/Auto Download/DTR: Q7.1 (E1), R37.1; also elsewhere on the board
/Auto Download/RTS: Q7.4 (E2), R34.1; also elsewhere on the board
/BOOT: R36.2, SW1.2; also elsewhere on the board
/CHIP_PU: R39.2, SW2.2; also elsewhere on the board
AGND: SW1.1, SW2.1; also elsewhere on the board
unnamed: Q7.2 (B1), R34.2
unnamed: Q7.6 (C1), R36.1
unnamed: Q7.5 (B2), R38.2
unnamed: Q7.3 (C2), R39.1
unnamed: R37.2, R38.1

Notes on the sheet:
Auto Download

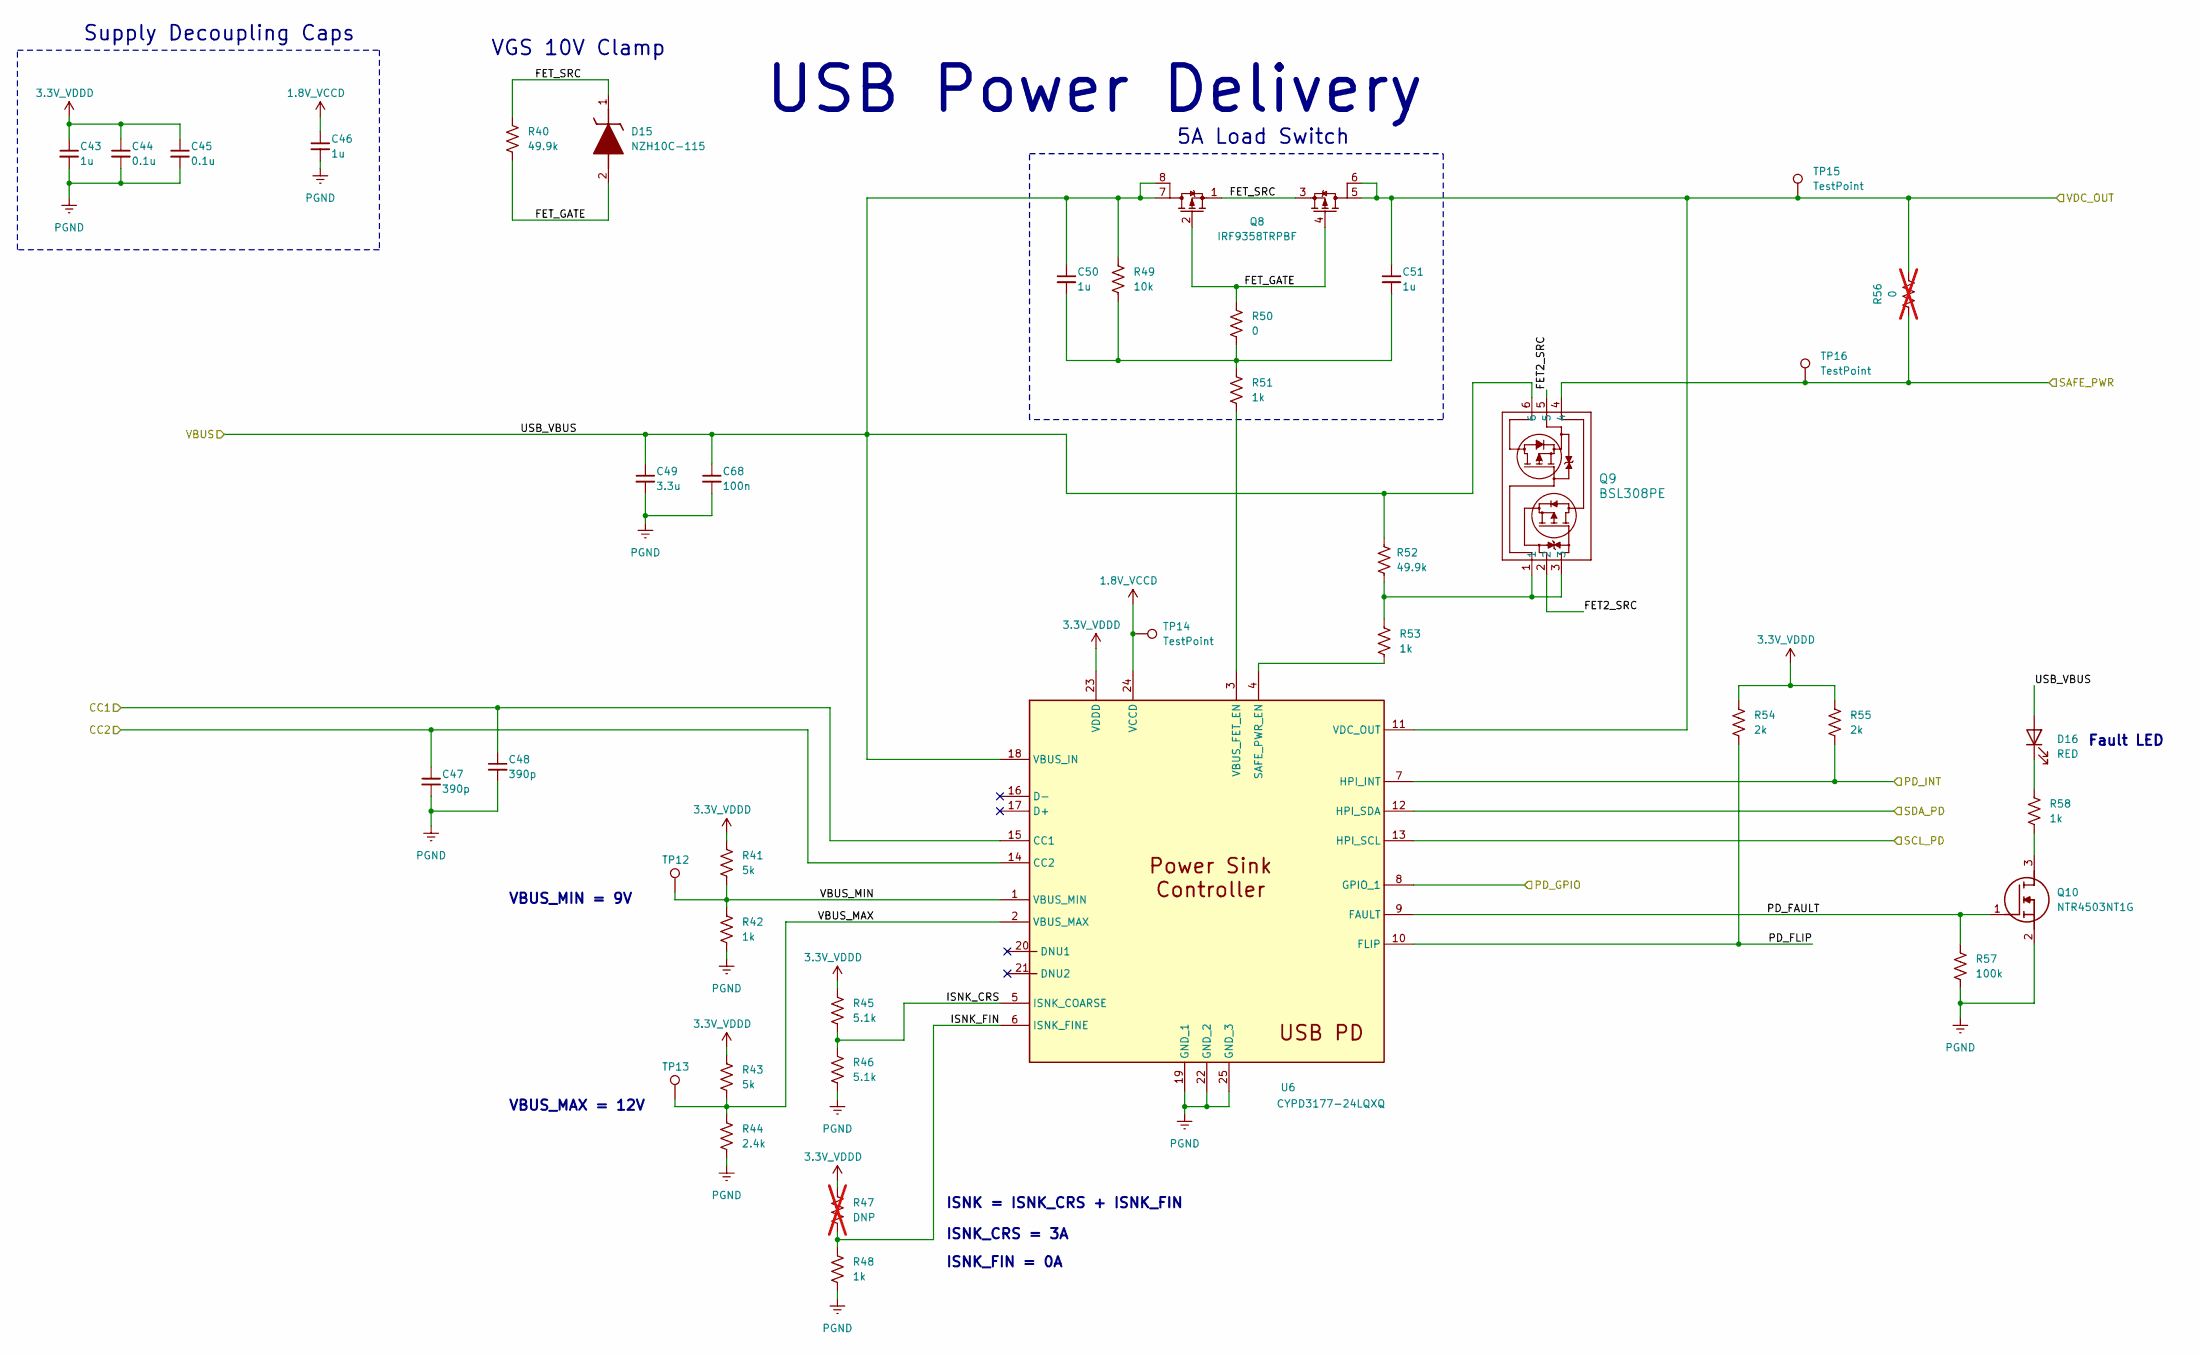
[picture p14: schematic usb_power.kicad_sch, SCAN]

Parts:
C43, C46: 1u; C_0603_1608Metric
C44, C45: 0.1u; C_0402_1005Metric
C47, C48: 390p; C_0603_1608Metric
C49: 3.3u; C_1210_3225Metric
C50, C51: 1u; C_0402_1005Metric
C68: 100n; C_0402_1005Metric
D15: NZH10C-115; SODFL3516X120N; Manufacturer_Part_Number NZH10C,115
D16: RED; LED_0603_1608Metric
Q8: IRF9358TRPBF; SO8_IRF9358TRPBF_INF; Manufacturer_Part_Number DMP3056LSD-13
Q9: BSL308PE; PG-TSOP6-6-4_INF
Q10: NTR4503NT1G; SOT23_318-08_ONS
R40, R52: 49.9k; R_0402_1005Metric
R41, R43: 5k; R_0603_1608Metric
R42, R48, R58: 1k; R_0603_1608Metric
R44: 2.4k; R_0603_1608Metric
R45, R46: 5.1k; R_0603_1608Metric
R47: DNP; R_0603_1608Metric; not fitted
R49: 10k; R_0402_1005Metric
R50: 0; R_0402_1005Metric
R51, R53: 1k; R_0402_1005Metric
R54, R55: 2k; R_0402_1005Metric
R56: 0; R_0805_2012Metric; not fitted
R57: 100k; R_0805_2012Metric
TP12, TP13, TP14, TP15, TP16: TestPoint; TestPoint_Pad_2.0x2.0mm
U6: CYPD3177-24LQXQ; QFN50P400X400X60-25N-D; Manufacturer_Part_Number CYPD3177-24LQXQ

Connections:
1.8V_VCCD: C46.1, TP14.1, U6.24 (VCCD)
3.3V_VDDD: C43.1, C44.1, C45.1, R41.1, R43.1, R45.1, R47.1, R54.1, R55.1, U6.23 (VDDD)
/I2C_SCL: U6.13 (HPI_SCL); also elsewhere on the board
/I2C_SDA: U6.12 (HPI_SDA); also elsewhere on the board
/PD_GPIO: U6.8 (GPIO_1); also elsewhere on the board
/PD_INT: R55.2, U6.7 (HPI_INT); also elsewhere on the board
/SAFE_PWR: Q9.4, R56.1, TP16.1
/USB Power Delivery/FET2_SRC: Q9.2, Q9.5
/USB Power Delivery/FET_GATE: D15.2 (A), Q8.2 (G1), Q8.4 (G2), R40.2, R50.1
/USB Power Delivery/FET_SRC: D15.1 (K), Q8.1 (S1), Q8.3 (S2), R40.1
/USB Power Delivery/ISNK_CRS: R45.2, R46.1, U6.5 (ISNK_COARSE)
/USB Power Delivery/ISNK_FIN: R47.2, R48.1, U6.6 (ISNK_FINE)
/USB Power Delivery/PD_FAULT: Q10.1 (G), R57.1, U6.9 (FAULT)
/USB Power Delivery/PD_FLIP: R54.2, U6.10 (FLIP)
/USB Power Delivery/VBUS_MAX: R43.2, R44.1, TP13.1, U6.2 (VBUS_MAX)
/USB Power Delivery/VBUS_MIN: R41.2, R42.1, TP12.1, U6.1 (VBUS_MIN)
/USB_CC1: C48.1, U6.15 (CC1); also elsewhere on the board
/USB_CC2: C47.1, U6.14 (CC2); also elsewhere on the board
/USB_VBUS: C49.1, C50.1, C68.1, D16.2 (A), Q8.7 (D1_1), Q8.8 (D1_2), Q9.6, R49.1, R52.1, U6.18 (VBUS_IN); also elsewhere on the board
/VDC: C51.1, Q8.5 (D2_1), Q8.6 (D2_2), R56.2, TP15.1, U6.11 (VDC_OUT); also elsewhere on the board
unnamed: C50.2, C51.2, R49.2, R50.2, R51.1
unnamed: D16.1 (K), R58.1
unnamed: Q9.1, Q9.3, R52.2, R53.1
unnamed: Q10.3 (D), R58.2
unnamed: R53.2, U6.4 (SAFE_PWR_EN)
unnamed: R51.2, U6.3 (VBUS_FET_EN)
PGND: C43.2, C44.2, C45.2, C46.2, C47.2, C48.2, C49.2, C68.2, Q10.2 (S), R42.2, R44.2, R46.2, R48.2, R57.2, U6.19 (GND_1), U6.22 (GND_2), U6.25 (GND_3); also elsewhere on the board

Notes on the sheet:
ISNK_CRS = 3A
VGS 10V Clamp
5A Load Switch
USB Power Delivery
Fault LED
ISNK = ISNK_CRS + ISNK_FIN
VBUS_MAX = 12V
Supply Decoupling Caps
VBUS_MIN = 9V
ISNK_FIN = 0A

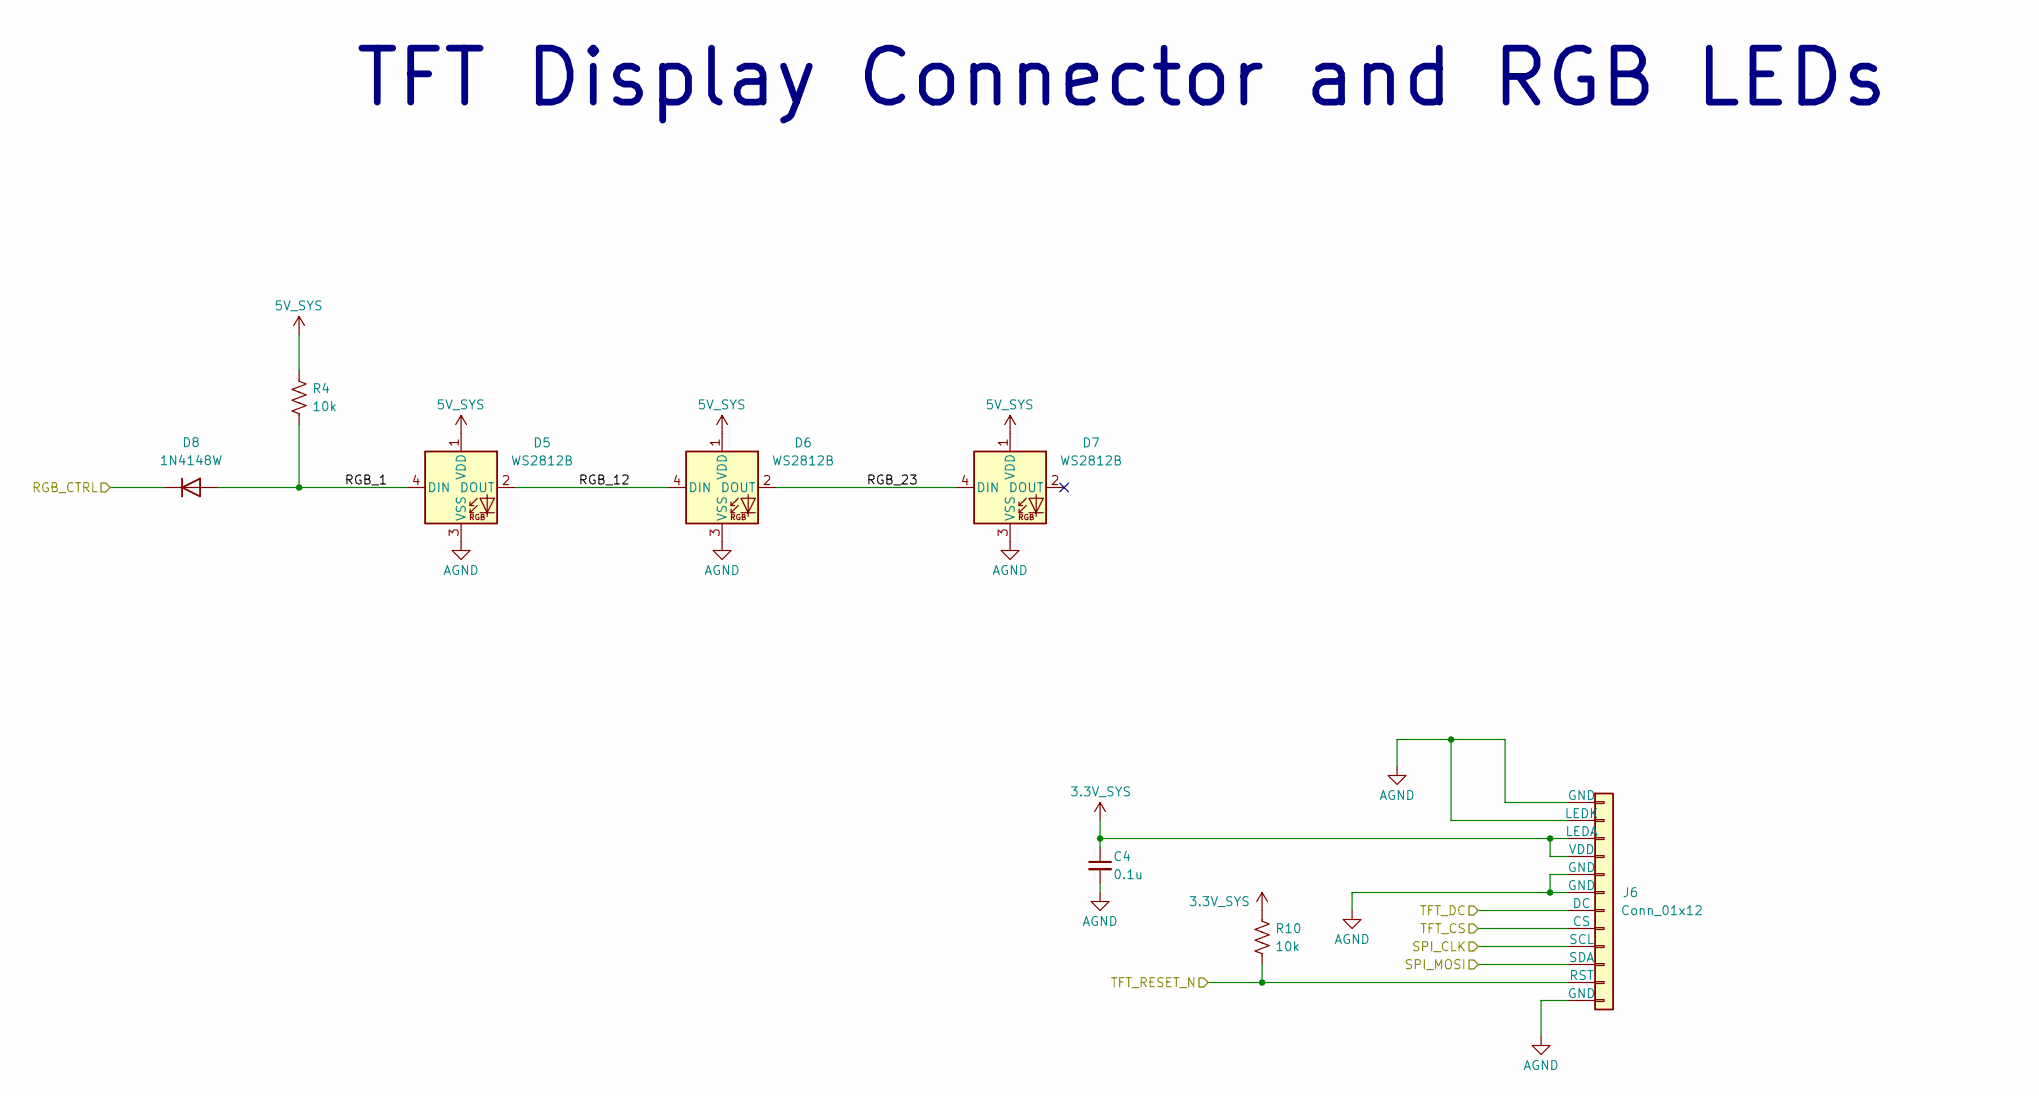
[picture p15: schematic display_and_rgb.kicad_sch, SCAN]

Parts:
C4: 0.1u; C_0603_1608Metric
D5, D6, D7: WS2812B; LED_WS2812B_PLCC4_5.0x5.0mm_P3.2mm
D8: 1N4148W; D_SOD-123
J6: Conn_01x12; 12-pin-0.7mm-FPC-Pad
R4, R10: 10k; R_0805_2012Metric

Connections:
5V_SYS: D5.1 (VDD), D6.1 (VDD), D7.1 (VDD), R4.1; also elsewhere on the board
/Display & RGB/RGB_1: D5.4 (DIN), D8.2 (A), R4.2
/Display & RGB/RGB_12: D5.2 (DOUT), D6.4 (DIN)
/Display & RGB/RGB_23: D6.2 (DOUT), D7.4 (DIN)
/SPI_CLK: J6.9 (SCL); also elsewhere on the board
/SPI_MOSI: J6.10 (SDA); also elsewhere on the board
/TFT_CS: J6.8 (CS); also elsewhere on the board
/TFT_DC: J6.7 (DC); also elsewhere on the board
AGND: C4.2, D5.3 (VSS), D6.3 (VSS), D7.3 (VSS), J6.1 (GND), J6.2 (LEDK), J6.5 (GND), J6.6 (GND), J6.12 (GND); also elsewhere on the board

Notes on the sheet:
TFT Display Connector and RGB LEDs

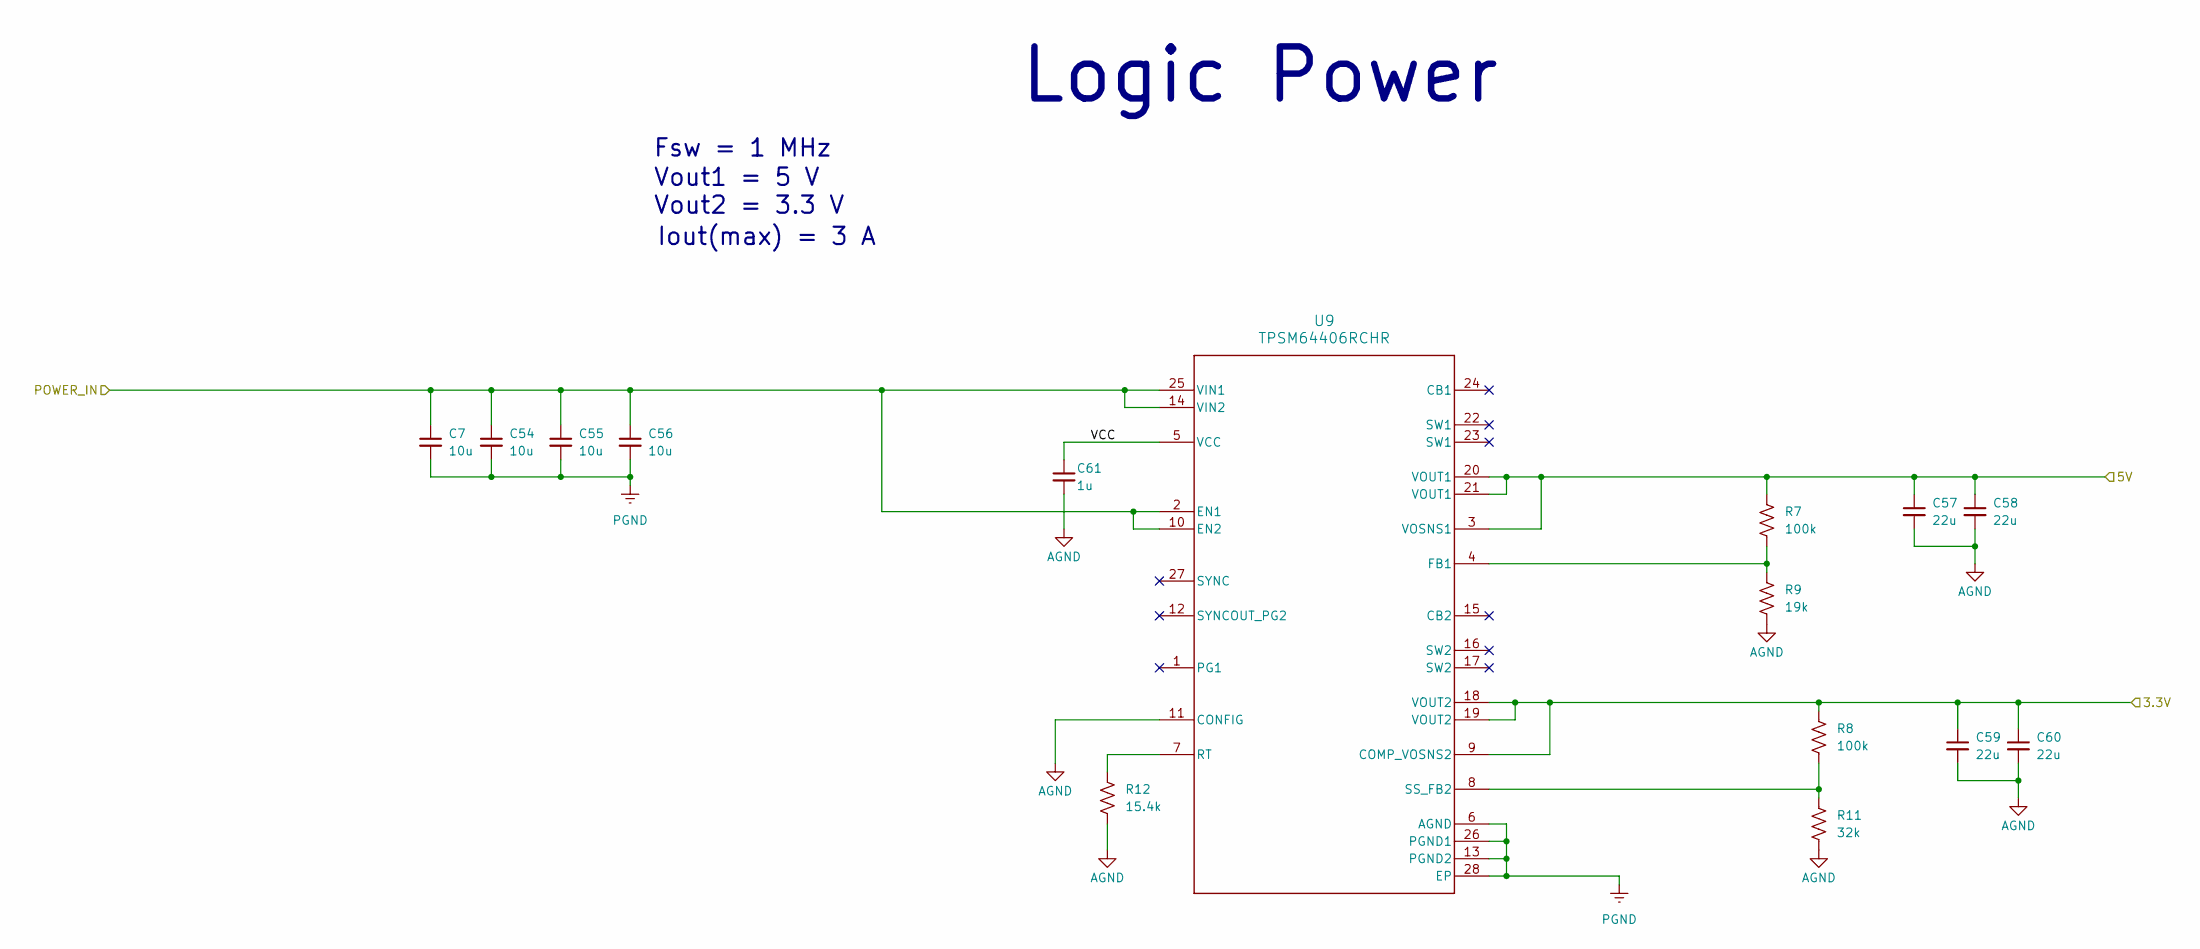
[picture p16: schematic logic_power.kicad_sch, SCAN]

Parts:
C7, C54, C55, C56: 10u; C_0805_2012Metric
C57, C58, C59, C60: 22u; C_1210_3225Metric
C61: 1u; C_0402_1005Metric
R7, R8: 100k; R_0402_1005Metric
R9: 19k; R_0402_1005Metric
R11: 32k; R_0402_1005Metric
R12: 15.4k; R_0805_2012Metric
U9: TPSM64406RCHR; RCH0028A-MFG

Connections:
5V_SYS: C57.1, C58.1, R7.1, U9.3 (VOSNS1), U9.20 (VOUT1), U9.21 (VOUT1); also elsewhere on the board
/Logic Power/VCC: C61.1, U9.5 (VCC)
/Power Management/PMID: C7.1, C54.1, C55.1, C56.1, U9.2 (EN1), U9.10 (EN2), U9.14 (VIN2), U9.25 (VIN1); also elsewhere on the board
AGND: C57.2, C58.2, C59.2, C60.2, C61.2, R9.2, R11.2, R12.2, U9.11 (CONFIG); also elsewhere on the board
unnamed: R7.2, R9.1, U9.4 (FB1)
unnamed: R12.1, U9.7 (RT)
unnamed: R8.2, R11.1, U9.8 (SS_FB2)
PGND: C7.2, C54.2, C55.2, C56.2, U9.6 (AGND), U9.13 (PGND2), U9.26 (PGND1), U9.28 (EP); also elsewhere on the board

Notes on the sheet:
Iout(max) = 3 A
Logic Power
Fsw = 1 MHz
Vout1 = 5 V Vout2 = 3.3 V

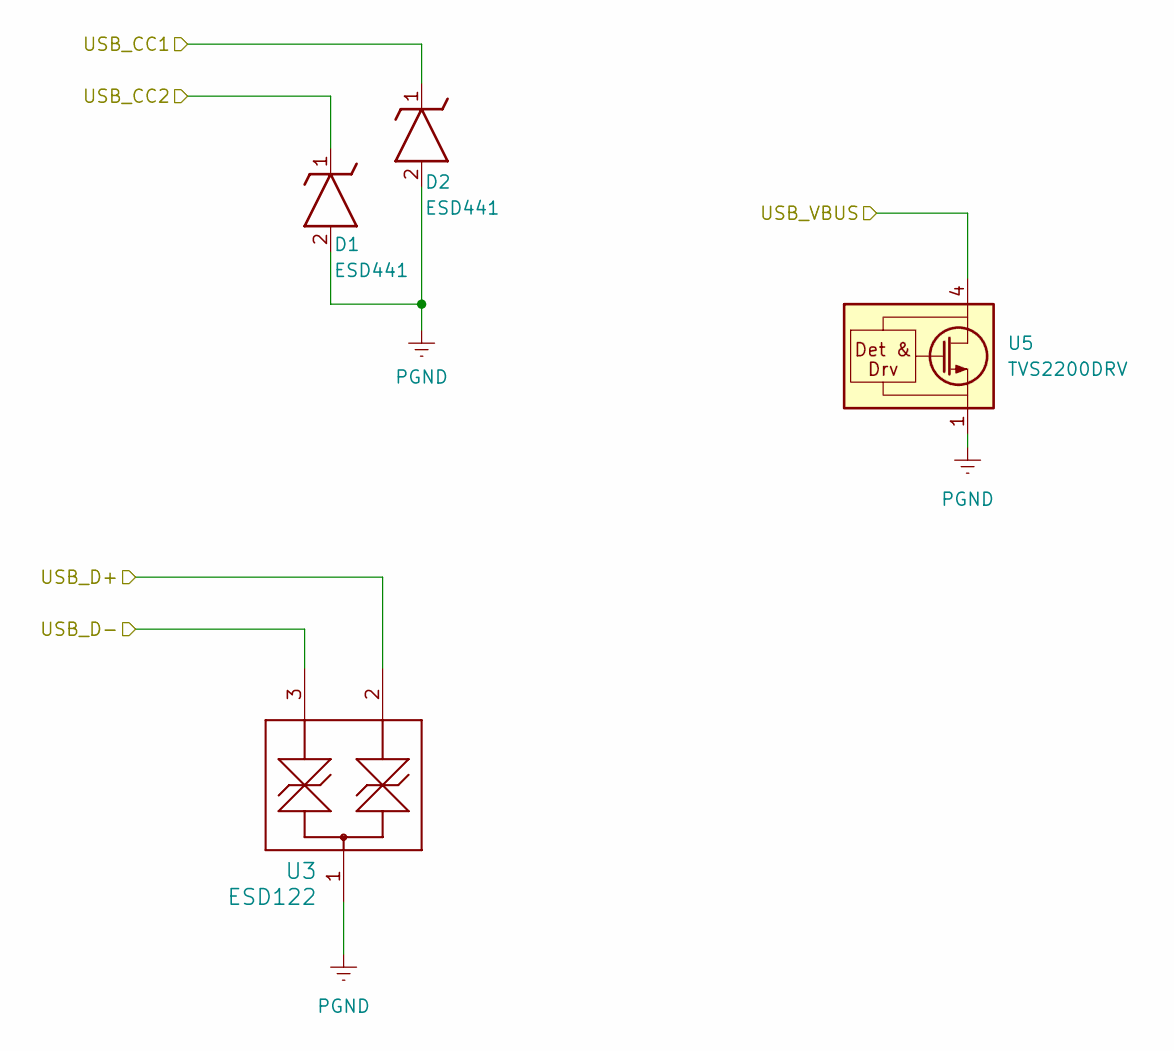
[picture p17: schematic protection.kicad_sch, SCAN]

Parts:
D1, D2: ESD441; X2SON2_DPL_TEX; Manufacturer_Part_Number ESD441DPLR
U3: ESD122; DMY0003A
U5: TVS2200DRV; WSON-6-1EP_2x2mm_P0.65mm_EP1x1.6mm

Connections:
/USB_CC1: D2.1; also elsewhere on the board
/USB_CC2: D1.1; also elsewhere on the board
/USB_D+: U3.2; also elsewhere on the board
/USB_D-: U3.3; also elsewhere on the board
/USB_VBUS: U5.4 (IN), U5.5 (IN), U5.6 (IN); also elsewhere on the board
PGND: D1.2, D2.2, U3.1, U5.1 (GND), U5.2 (GND), U5.3 (GND), U5.7 (GND); also elsewhere on the board

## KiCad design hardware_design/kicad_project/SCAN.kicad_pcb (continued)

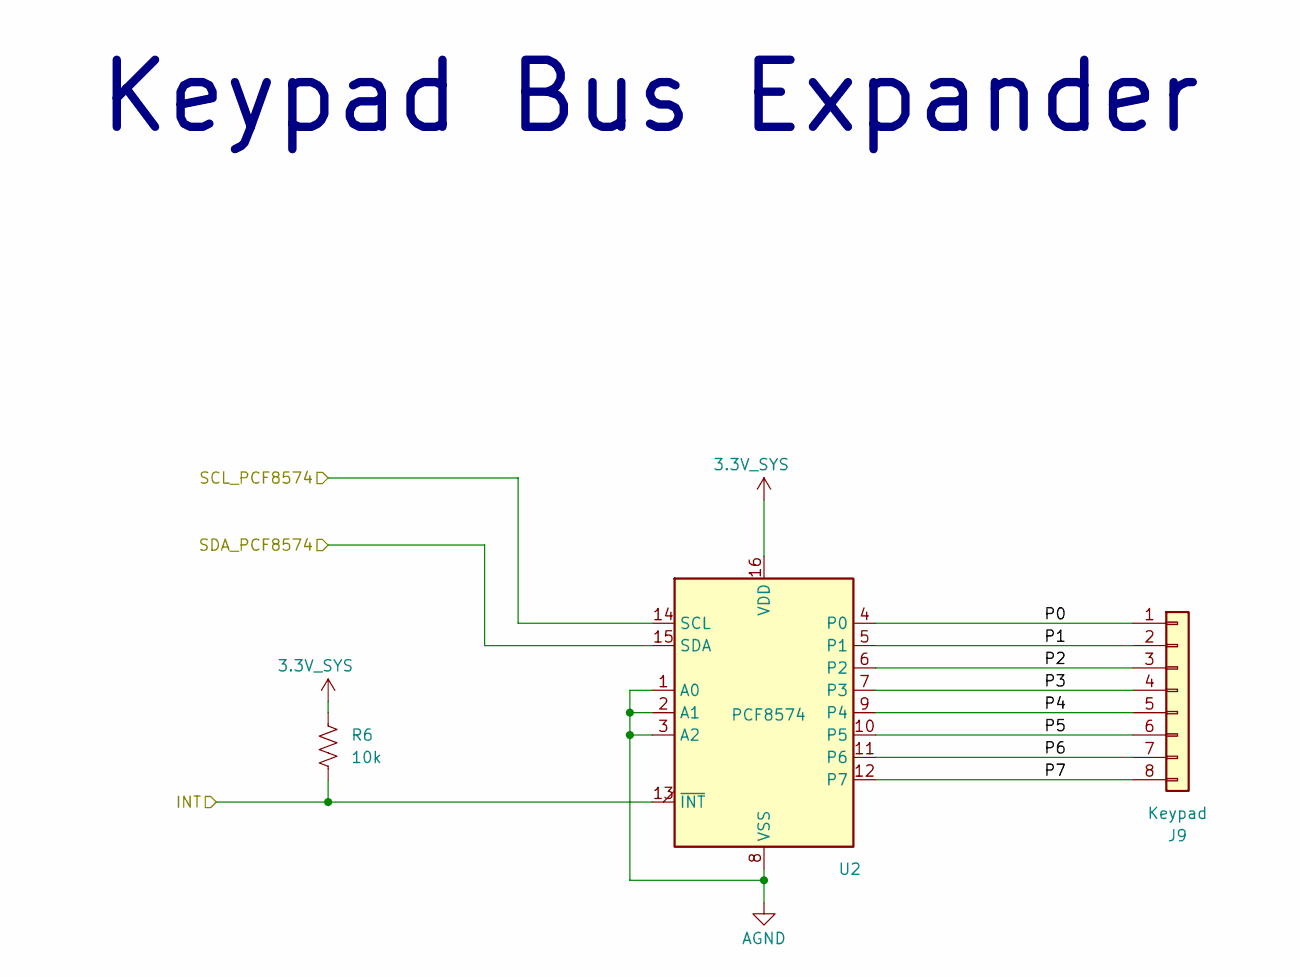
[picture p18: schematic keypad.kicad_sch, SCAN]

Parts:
J9: Keypad; PinHeader_1x08_P2.54mm_Vertical
R6: 10k; R_0805_2012Metric
U2: PCF8574; DIP794W45P254L1969H508Q16

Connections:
/I2C_SCL: U2.14 (SCL); also elsewhere on the board
/I2C_SDA: U2.15 (SDA); also elsewhere on the board
/KEYPAD_INT: R6.2, U2.13 (~INT); also elsewhere on the board
/Keypad/P0: J9.1, U2.4 (P0)
/Keypad/P1: J9.2, U2.5 (P1)
/Keypad/P2: J9.3, U2.6 (P2)
/Keypad/P3: J9.4, U2.7 (P3)
/Keypad/P4: J9.5, U2.9 (P4)
/Keypad/P5: J9.6, U2.10 (P5)
/Keypad/P6: J9.7, U2.11 (P6)
/Keypad/P7: J9.8, U2.12 (P7)
AGND: U2.1 (A0), U2.2 (A1), U2.3 (A2), U2.8 (VSS); also elsewhere on the board

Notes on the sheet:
Keypad Bus Expander

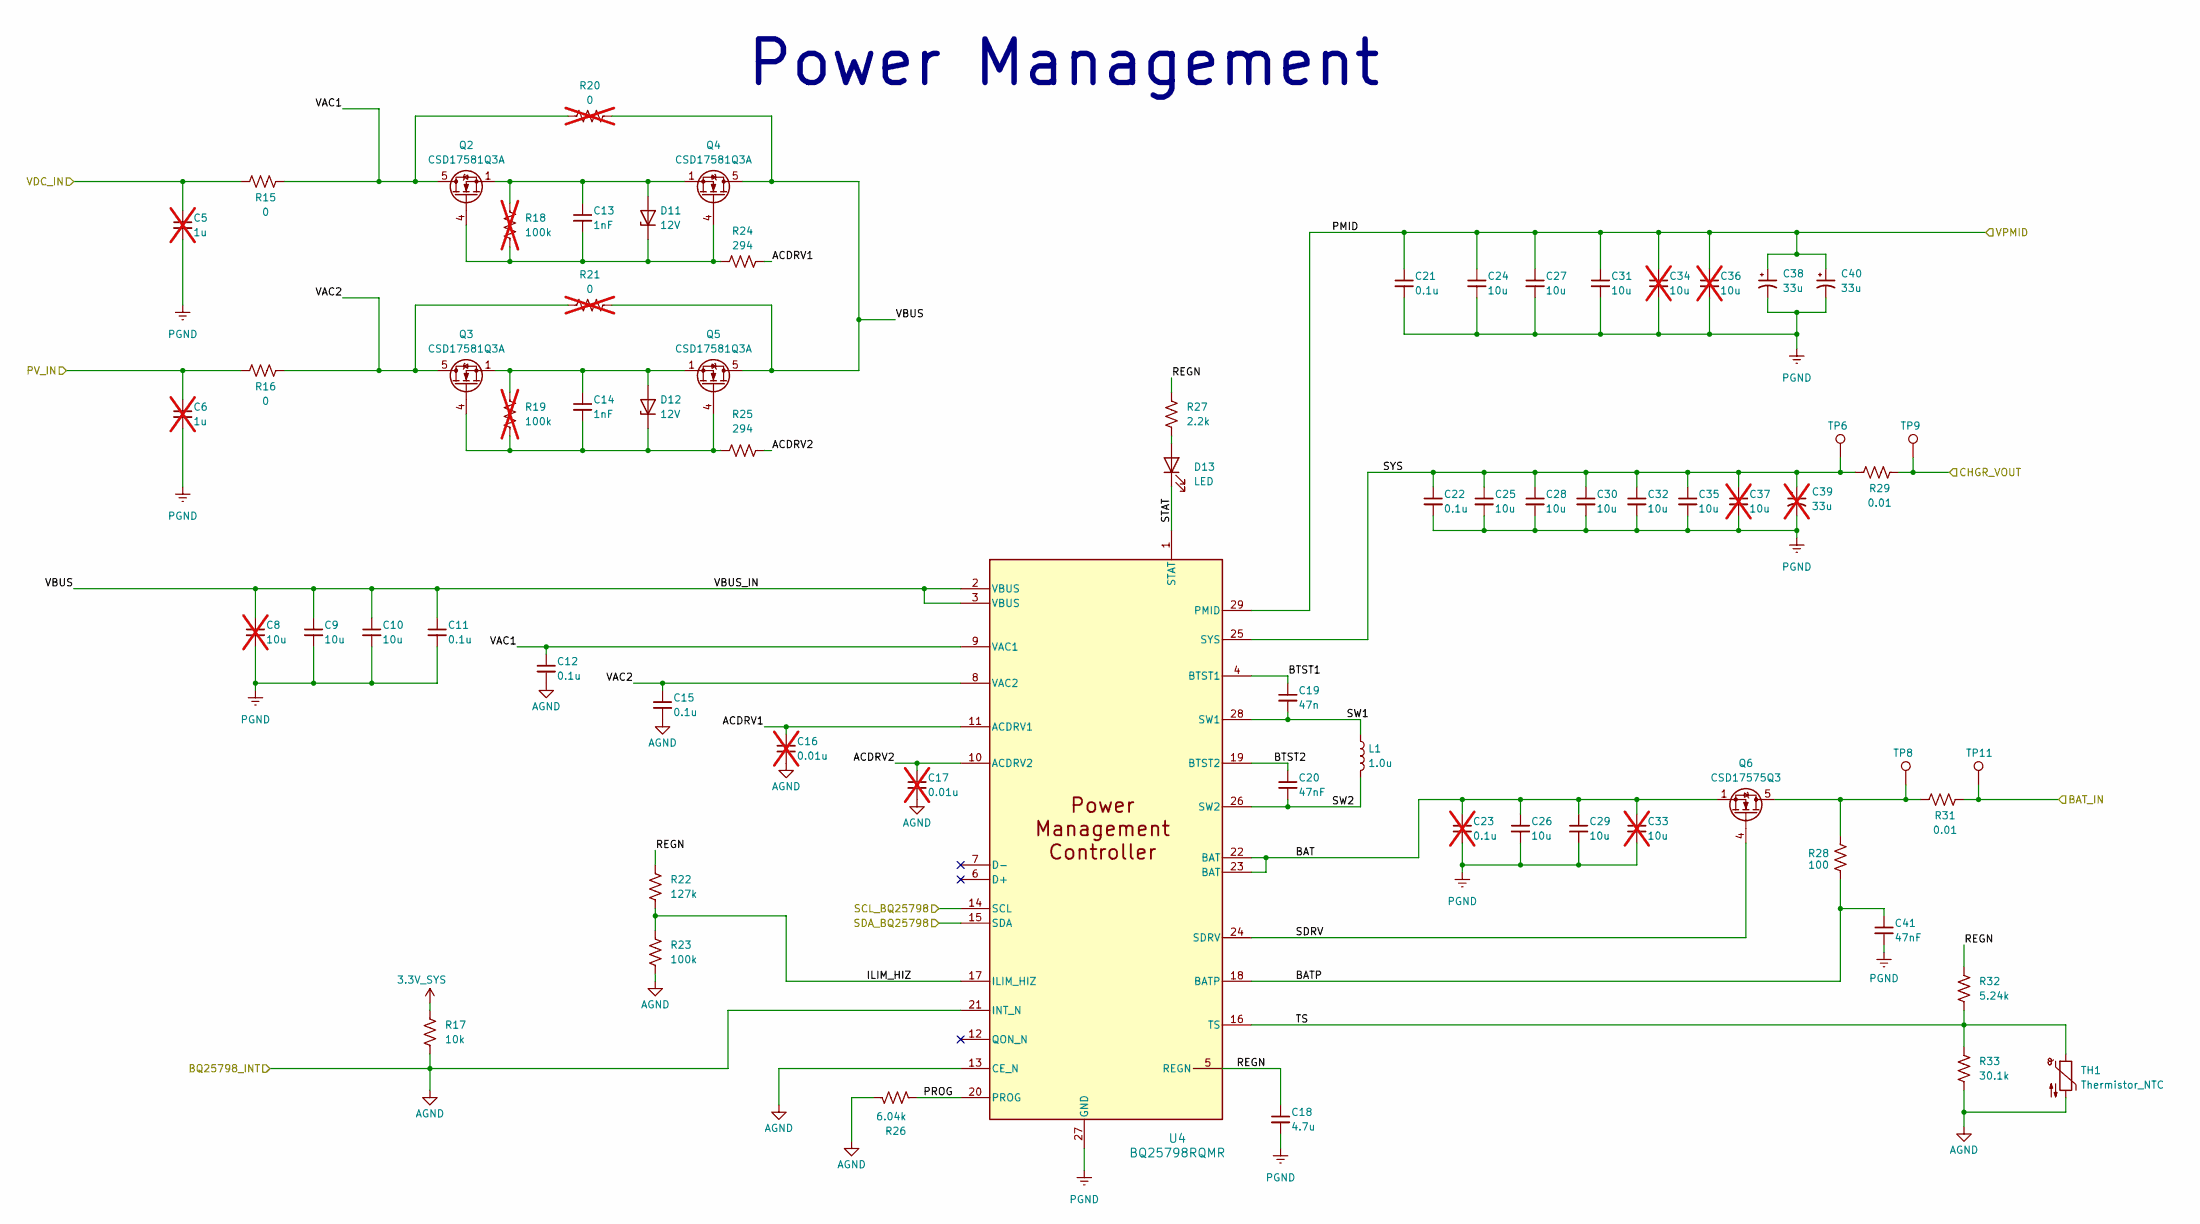
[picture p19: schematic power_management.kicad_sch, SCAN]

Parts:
C5, C6: 1u; C_0805_2012Metric; not fitted
C8, C34, C36, C37: 10u; C_0805_2012Metric; not fitted
C9, C10, C24, C25, C27, C28, C30, C31, C32, C35: 10u; C_0805_2012Metric
C11, C12, C15, C21, C22: 0.1u; C_0402_1005Metric
C13, C14: 1nF; C_0402_1005Metric
C16, C17: 0.01u; C_0402_1005Metric; not fitted
C18: 4.7u; C_0603_1608Metric
C19: 47n; C_0402_1005Metric
C20, C41: 47nF; C_0402_1005Metric
C23: 0.1u; C_0402_1005Metric; not fitted
C26, C29: 10u; C_0603_1608Metric
C33: 10u; C_0603_1608Metric; not fitted
C38, C40: 33u; CP_EIA-7343-31_Kemet-D
C39: 33u; CP_EIA-7343-31_Kemet-D; not fitted
D11, D12: 12V; D_SOD-523
D13: LED; LED_0805_2012Metric
L1: 1.0u; SPM6530
Q2, Q3, Q4, Q5: CSD17581Q3A; VSON-8_3.3x3.3mm_P0.65mm_NexFET
Q6: CSD17575Q3; VSON-8_3.3x3.3mm_P0.65mm_NexFET
R15, R16: 0; R_2010_5025Metric
R17: 10k; R_0805_2012Metric
R18, R19: 100k; R_0402_1005Metric; not fitted
R20, R21: 0; R_0805_2012Metric; not fitted
R22: 127k; R_0603_1608Metric
R23: 100k; R_0603_1608Metric
R24, R25: 294; R_0603_1608Metric
R26: 6.04k; R_0603_1608Metric
R27: 2.2k; R_0402_1005Metric
R28: 100; R_0603_1608Metric
R29, R31: 0.01; R_2010_5025Metric
R32: 5.24k; R_0402_1005Metric
R33: 30.1k; R_0402_1005Metric
TH1: Thermistor_NTC; R_Radial_Power_L11.0mm_W7.0mm_P5.00mm
TP6, TP8, TP9, TP11: TestPoint; TestPoint_Pad_2.0x2.0mm
U4: BQ25798RQMR; IC_BQ25798RQMR

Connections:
/CHGR_VOUT: R29.2, TP9.1
/I2C_SCL: U4.14 (SCL); also elsewhere on the board
/I2C_SDA: U4.15 (SDA); also elsewhere on the board
/Power Management/ACDRV1: C16.1, R24.2, U4.11 (ACDRV1)
/Power Management/ACDRV2: C17.1, R25.2, U4.10 (ACDRV2)
/Power Management/BAT: C23.1, C26.1, C29.1, C33.1, Q6.1 (S), Q6.2 (S), Q6.3 (S), U4.22 (BAT), U4.23 (BAT)
/Power Management/BATP: C41.1, R28.1, U4.18 (BATP)
/Power Management/BAT_IN: R31.2, TP11.1; also elsewhere on the board
/Power Management/BTST1: C19.1, U4.4 (BTST1)
/Power Management/BTST2: C20.1, U4.19 (BTST2)
/Power Management/ILIM_HIZ: R22.2, R23.1, U4.17 (ILIM_HIZ)
/Power Management/PMID: C21.1, C24.1, C27.1, C31.1, C34.1, C36.1, C38.1, C40.1, U4.29 (PMID); also elsewhere on the board
/Power Management/PROG: R26.2, U4.20 (PROG)
/Power Management/PV_IN: C6.1, R16.1; also elsewhere on the board
/Power Management/REGN: C18.1, R22.1, R27.1, R32.1, U4.5 (REGN)
/Power Management/SDRV: Q6.4 (G), U4.24 (SDRV)
/Power Management/STAT: D13.1 (K), U4.1 (STAT)
/Power Management/SW1: C19.2, L1.1, U4.28 (SW1)
/Power Management/SW2: C20.2, L1.2, U4.26 (SW2)
/Power Management/SYS: C22.1, C25.1, C28.1, C30.1, C32.1, C35.1, C37.1, C39.1, R29.1, TP6.1, U4.25 (SYS)
/Power Management/TS: R32.2, R33.1, TH1.1, U4.16 (TS)
/Power Management/VAC1: C12.1, Q2.5 (D), R15.2, R20.1, U4.9 (VAC1)
/Power Management/VAC2: C15.1, Q3.5 (D), R16.2, R21.1, U4.8 (VAC2)
/Power Management/VBUS: C8.1, C9.1, C10.1, C11.1, Q4.5 (D), Q5.5 (D), R20.2, R21.2, U4.2 (VBUS), U4.3 (VBUS)
/VDC: C5.1, R15.1; also elsewhere on the board
AGND: C12.2, C15.2, C16.2, C17.2, R17.2, R23.2, R26.1, R33.2, TH1.2, U4.13 (CE_N), U4.21 (INT_N); also elsewhere on the board
unnamed: C13.1, D11.2 (A), Q2.1 (S), Q2.2 (S), Q2.3 (S), Q4.1 (S), Q4.2 (S), Q4.3 (S), R18.1
unnamed: C13.2, D11.1 (K), Q2.4 (G), Q4.4 (G), R18.2, R24.1
unnamed: C14.1, D12.2 (A), Q3.1 (S), Q3.2 (S), Q3.3 (S), Q5.1 (S), Q5.2 (S), Q5.3 (S), R19.1
unnamed: C14.2, D12.1 (K), Q3.4 (G), Q5.4 (G), R19.2, R25.1
unnamed: D13.2 (A), R27.2
unnamed: Q6.5 (D), R28.2, R31.1, TP8.1
PGND: C5.2, C6.2, C8.2, C9.2, C10.2, C11.2, C18.2, C21.2, C22.2, C23.2, C24.2, C25.2, C26.2, C27.2, C28.2, C29.2, C30.2, C31.2, C32.2, C33.2, C34.2, C35.2, C36.2, C37.2, C38.2, C39.2, C40.2, C41.2, U4.27 (GND); also elsewhere on the board

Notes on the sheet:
Power Management

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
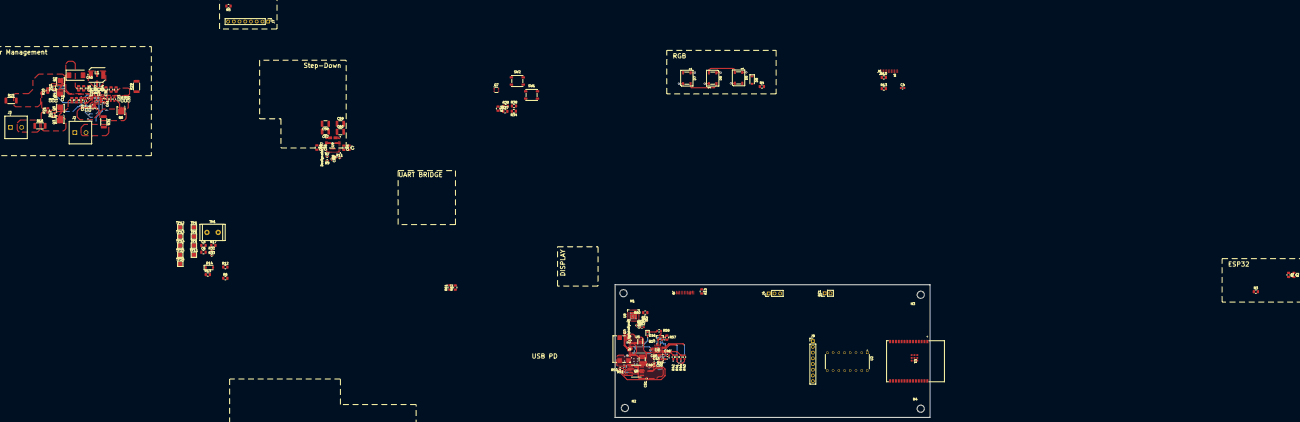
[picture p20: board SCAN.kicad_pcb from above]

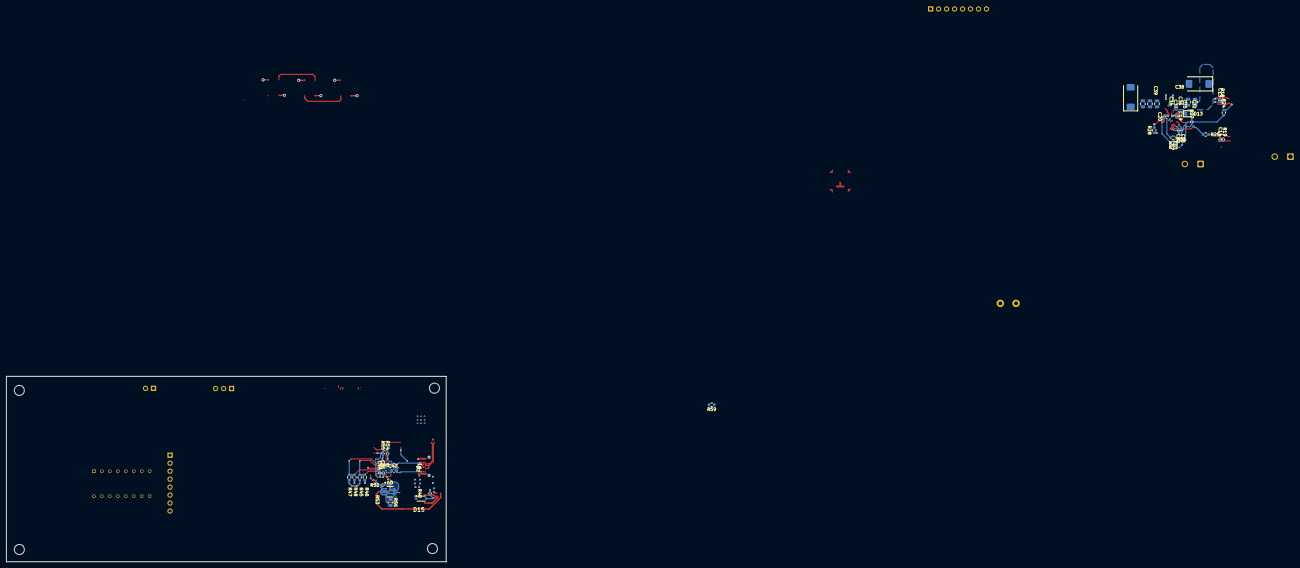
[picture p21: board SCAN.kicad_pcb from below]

Board: 4 copper layers, 140.0 x 59.0 mm, 177 parts (42 on the bottom side), 107 nets.

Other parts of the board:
C53, C63: 0.1u; C_0402_1005Metric
C62: 1.0u; C_0603_1608Metric
D14: 1N4148W; D_SOD-123
J7: Conn_01x08; PinHeader_1x08_P2.54mm_Vertical
J8: Conn_01x12; 12-pin-0.7mm-FPC-Pad
R5, R10#2, R60: 10k; R_0805_2012Metric
R13#2: 3.3k; R_0805_2012Metric
R14: 22.1k; R_0603_1608Metric
R30: 47.5k; R_0603_1608Metric
R59: 4.7k; R_0603_1608Metric
R61, R62: 0; R_0805_2012Metric
U8: CP2102N-A02-xQFN28; QFN-28-1EP_5x5mm_P0.5mm_EP3.35x3.35mm

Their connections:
5V_SYS: C62.1, C63.1, R14.2, U8.7 (VREGIN); also elsewhere on the board
/Auto Download/DTR: U8.28 (~DTR); also elsewhere on the board
/Auto Download/RTS: U8.24 (~RTS); also elsewhere on the board
/NFC_INT: J7.7; also elsewhere on the board
/NFC_RST: J7.8, R5.1; also elsewhere on the board
/SPI_CLK: J7.1, J8.9 (SCL); also elsewhere on the board
/SPI_CS: J7.4; also elsewhere on the board
/SPI_MISO: J7.2; also elsewhere on the board
/SPI_MOSI: J7.3, J8.10 (SDA); also elsewhere on the board
/TFT_CS: J8.8 (CS); also elsewhere on the board
/TFT_DC: J8.7 (DC); also elsewhere on the board
/UART_RXD: R62.2; also elsewhere on the board
/UART_TXD: R61.2; also elsewhere on the board
/USB-to-UART Bridge/RST: R59.2, U8.9 (~RST)
/USB-to-UART Bridge/RXD: R62.1, U8.25 (RXD)
/USB-to-UART Bridge/SUSPEND: R60.1, U8.11 (~SUSPEND)
/USB-to-UART Bridge/TXD: R61.1, U8.26 (TXD)
/USB-to-UART Bridge/VBUS_SNS: R14.1, R30.2, U8.8 (VBUS)
/USB-to-UART Bridge/VDD: C53.1, R59.1, U8.6 (VDD)
/USB_D+: U8.4 (D+); also elsewhere on the board
/USB_D-: U8.5 (D-); also elsewhere on the board
AGND: C53.2, C62.2, C63.2, J7.6, J8.1 (GND), J8.2 (LEDK), J8.5 (GND), J8.6 (GND), J8.12 (GND), R30.1, R60.2, U8.3 (GND), U8.29 (GND); also elsewhere on the board

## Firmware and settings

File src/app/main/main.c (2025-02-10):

#include <stdio.h>
#include "freertos/FreeRTOS.h"
#include "freertos/task.h"
#include "freertos/queue.h"
#include "freertos/event_groups.h"
#include "esp_system.h"
#include "driver/gpio.h"
#include "esp_log.h"
#include "led_strip.h"
#include "sdkconfig.h"
#include "nvs_flash.h"

#include "main.h"
#include "wifi_init.h"
#include "ota.h"
#include "firebase_http_client.h"
#include "firebase_utils.h"

#include "freertos/semphr.h"
#include "esp_heap_task_info.h"

#define BLINK_GPIO 8

// Define states
typedef enum {
    STATE_WIFI_INIT,
    STATE_WIFI_READY,
    STATE_ERROR,
} kiosk_state_t;

static kiosk_state_t current_state = STATE_WIFI_INIT;

// Task Handles
static TaskHandle_t blink_led_task_handle = NULL;
static TaskHandle_t wifi_init_task_handle = NULL;
static TaskHandle_t ota_update_task_handle = NULL;
static TaskHandle_t database_task_handle = NULL;

// not static because it is being used in wifi_init.c as extern variable
SemaphoreHandle_t wifi_init_semaphore = NULL;  // Semaphore to signal Wi-Fi init completion

static const char *TAG = "MAIN";

static uint8_t s_led_state = 0;

static led_strip_handle_t led_strip;


void blink_led_task(void *pvParameter)
{
    while(1) {
        s_led_state = !s_led_state;
        
        if (current_state == STATE_WIFI_INIT) {
            vTaskDelay(200 / portTICK_PERIOD_MS);
        }
        else {
            vTaskDelay(1200 / portTICK_PERIOD_MS);
        }

        /* If the addressable LED is enabled */
        if (s_led_state) {
            /* Set the LED pixel using RGB from 0 (0%) to 255 (100%) for each color */
            if (current_state == STATE_WIFI_INIT) {
                led_strip_set_pixel(led_strip, 0, 100, 0, 0);
            }
            else {
                led_strip_set_pixel(led_strip, 0, 0, 0, 50);
            }
            /* Refresh the strip to send data */
            led_strip_refresh(led_strip);
        } else {
            /* Set all LED off to clear all pixels */
            led_strip_clear(led_strip);
        }
    }
}

static void configure_led(void)
{
    ESP_LOGI(TAG, "Configured to blink addressable LED!");
    /* LED strip initialization with the GPIO and pixels number*/
    led_strip_config_t strip_config = {
        .strip_gpio_num = BLINK_GPIO,
        .max_leds = 1, // at least one LED on board
    };

    led_strip_rmt_config_t rmt_config = {
        .resolution_hz = 10 * 1000 * 1000, // 10MHz
        .flags.with_dma = false,
    };
    ESP_ERROR_CHECK(led_strip_new_rmt_device(&strip_config, &rmt_config, &led_strip));

    /* Set all LED off to clear all pixels */
    led_strip_clear(led_strip);
}

// Function to control state transitions and task management
void state_control_task(void *pvParameter) {
    while(1) {
        // ESP_LOGI("Memory", "Free heap size: %lu bytes", (unsigned long)esp_get_free_heap_size());

        switch (current_state) {
            case STATE_WIFI_INIT:
                // Start Wi-Fi init task if not already started
                if (wifi_init_task_handle == NULL) {
                    ESP_LOGI(TAG, "Starting Wi-Fi Init Task");
                    xTaskCreate(wifi_init_task, "wifi_init_task", 4096, NULL, 4, &wifi_init_task_handle);
                }

                // Start LED blinking task if not already running
                if (blink_led_task_handle == NULL) {
                    ESP_LOGI(TAG, "Starting Blink LED Task");
                    xTaskCreate(blink_led_task, "blink_led_task", 1024, NULL, 2, &blink_led_task_handle);
                }



                // Check if Wi-Fi init is completed (signaled by semaphore)
                if (xSemaphoreTake(wifi_init_semaphore, portMAX_DELAY) == pdTRUE) {
                    current_state = STATE_WIFI_READY;  // Transition state outside of the task
                }

                break;

            case STATE_WIFI_READY:
                // Stop Wi-Fi task when ready
                if (wifi_init_task_handle != NULL) {
                    vTaskDelete(wifi_init_task_handle);
                    wifi_init_task_handle = NULL;
                }
                // ESP_LOGI(TAG, "Wi-Fi Initialized. Ready!");

                //if (blink_led_task_handle != NULL) {
                //    vTaskDelete(blink_led_task_handle);
                //    blink_led_task_handle = NULL;
                //}
/*
                if (ota_update_task_handle == NULL) {
                    ESP_LOGI(TAG, "Creating OTA update task");
                    xTaskCreate(ota_update_fw_task, "OTA UPDATE TASK", 1024 * 4, NULL, 8, &ota_update_task_handle);
                }
*/



                if (database_task_handle == NULL) {
                    const char *user_id = "5387541";
                    ESP_LOGI(TAG, "Creating check-in task");
                    xTaskCreate(check_in_user_task, "CHECK IN TASK", 1024 * 12, (void *)user_id, 8, &database_task_handle);
                }

                break;

            case STATE_ERROR:
                // Handle error state - for now just stopping all tasks
                if (wifi_init_task_handle != NULL) {
                    vTaskDelete(wifi_init_task_handle);
                    wifi_init_task_handle = NULL;
                }
                if (blink_led_task_handle != NULL) {
                    vTaskDelete(blink_led_task_handle);
                    blink_led_task_handle = NULL;
                }
                ESP_LOGE(TAG, "Error state reached!");
                break;

            default:
                ESP_LOGW(TAG, "Unknown state encountered: %d", current_state);
                break;
        }
    vTaskDelay(500 / portTICK_PERIOD_MS);
    }
    ESP_LOGI(TAG, "State control task finished");  // Should not reach here unless task is deleted
}

void app_main(void)
{
    ESP_LOGI(TAG, "App Main Start");

    //Initialize NVS
    esp_err_t ret = nvs_flash_init();
    if (ret == ESP_ERR_NVS_NO_FREE_PAGES || ret == ESP_ERR_NVS_NEW_VERSION_FOUND) {
        // 1.OTA app partition table has a smaller NVS partition size than the non-OTA
        // partition table. This size mismatch may cause NVS initialization to fail.
        // 2.NVS partition contains data in new format and cannot be recognized by this version of code.
        // If this happens, we erase NVS partition and initialize NVS again.
      ESP_ERROR_CHECK(nvs_flash_erase());
      ret = nvs_flash_init();
    }
    ESP_ERROR_CHECK(ret);
    // ESP_ERROR_CHECK( heap_trace_init_standalone( trace_record, NUM_RECORDS ) );
    // ESP_LOGI("Memory", "STARTING FREE HEAP SIZE: %lu bytes", (long unsigned int)esp_get_free_heap_size());
    /* Configure the peripheral according to the LED type */
    configure_led();

    // Create semaphore for signaling Wi-Fi init completion
    wifi_init_semaphore = xSemaphoreCreateBinary();

    xTaskCreate(state_control_task, "state_control_task", 4096 * 2, NULL, 3, NULL);

    while(1){
        vTaskDelay(4000 / portTICK_PERIOD_MS);
    }
}

/*

#define PROXIMITY_DETECTED BIT0
#define NFC_READ_SUCCESS BIT1
#define NFC_VALIDATED BIT2

static EventGroupHandle_t event_group;

typedef enum {
    STATE_IDLE,
    STATE_USER_DETECTED,
    STATE_READING_NFC,
    STATE_VALIDATING,
    STATE_DISPLAY_RESULT
} state_t;

static state_t current_state = STATE_IDLE;

// Task to handle proximity sensor
void proximity_task(void *param) {
    while (1) {
        if (proximity_sensor_detected()) {
            xEventGroupSetBits(event_group, PROXIMITY_DETECTED);
        }
        vTaskDelay(pdMS_TO_TICKS(500)); // Check every 500 ms
    }
}

// Task to handle NFC reading
void nfc_task(void *param) {
    while (1) {
        xEventGroupWaitBits(event_group, PROXIMITY_DETECTED, pdTRUE, pdFALSE, portMAX_DELAY);
        if (nfc_read_data()) {
            xEventGroupSetBits(event_group, NFC_READ_SUCCESS);
        }
    }
}

// Task to validate NFC data online
void validation_task(void *param) {
    while (1) {
        xEventGroupWaitBits(event_group, NFC_READ_SUCCESS, pdTRUE, pdFALSE, portMAX_DELAY);
        bool valid = database_validate_nfc();
        if (valid) {
            xEventGroupSetBits(event_group, NFC_VALIDATED);
        }
        current_state = STATE_DISPLAY_RESULT;
    }
}

// Task to update the display based on validation result
void display_task(void *param) {
    while (1) {
        xEventGroupWaitBits(event_group, NFC_VALIDATED, pdTRUE, pdFALSE, portMAX_DELAY);
        display_show_result(true);  // Show success
        vTaskDelay(pdMS_TO_TICKS(5000));  // Display result for 5 seconds
        current_state = STATE_IDLE;
    }
}

// Main State Machine
void app_main(void) {
    // Initialize event group
    event_group = xEventGroupCreate();

    // Initialize hardware and network
    nfc_reader_init();
    display_init();
    wifi_init();
    sensor_init();

    // Create tasks
    xTaskCreate(proximity_task, "Proximity Task", 2048, NULL, 1, NULL);
    xTaskCreate(nfc_task, "NFC Task", 4096, NULL, 1, NULL);
    xTaskCreate(validation_task, "Validation Task", 4096, NULL, 1, NULL);
    xTaskCreate(display_task, "Display Task", 2048, NULL, 1, NULL);

    while (1) {
        switch (current_state) {
            case STATE_IDLE:
                // Wait until proximity is detected
                xEventGroupWaitBits(event_group, PROXIMITY_DETECTED, pdTRUE, pdFALSE, portMAX_DELAY);
                current_state = STATE_USER_DETECTED;
                break;

            case STATE_USER_DETECTED:
                // Wait until NFC data is read
                xEventGroupWaitBits(event_group, NFC_READ_SUCCESS, pdTRUE, pdFALSE, portMAX_DELAY);
                current_state = STATE_READING_NFC;
                break;

            case STATE_READING_NFC:
                // Move to validation state after NFC read
                current_state = STATE_VALIDATING;
                break;

            case STATE_VALIDATING:
                // Wait until NFC validation completes
                xEventGroupWaitBits(event_group, NFC_VALIDATED, pdTRUE, pdFALSE, portMAX_DELAY);
                current_state = STATE_DISPLAY_RESULT;
                break;

            case STATE_DISPLAY_RESULT:
                // Result is displayed; transition back to idle state after showing result
                current_state = STATE_IDLE;
                break;
        }

        vTaskDelay(pdMS_TO_TICKS(100)); // Small delay to prevent rapid state change
    }
}
*/

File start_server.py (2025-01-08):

import serial.tools.list_ports
import os
import sys
import subprocess
import time
import argparse
import psutil  # Import psutil to check for processes using a port

def list_serial_ports():
    ports = serial.tools.list_ports.comports()
    return ports

def get_current_directory():
    return os.getcwd()

def run_docker_command(is_flash=False):
    current_directory = get_current_directory()

    # Base Docker run command
    docker_command = [
       "docker", "run", "--rm", "--build", "-v", f"{current_directory}:/project", "-w", "/project", 
        "-e", "HOME=/tmp", "-it", "--name", "UCF-Senior-Design", "--file", "./Dockerfile", "espressif/idf"
    ]
    
    if is_flash:
        docker_command.append("idf.py")
        docker_command.extend(["--port", "rfc2217://host.docker.internal:4000?ign_set_control", "flash"])

    # Print the docker command that will be executed
    print(f"\nRunning Docker command:\n{' '.join(docker_command)}\n")

    # Wait for 1 second before executing the command
    time.sleep(1)

    # Run Docker command in the same terminal
    subprocess.run(docker_command)

def run_rfc2217_server(serial_port):
    print(f"\nStarting RFC2217 server on {serial_port}...\n")
    rfc_command = ["python", "esp_rfc2217_server.py", "-v", "-p", "4000", serial_port]
    
    # Run RFC2217 server in the background and capture output
    try:
        rfc_process = subprocess.Popen(rfc_command, stdout=subprocess.PIPE, stderr=subprocess.PIPE)
        time.sleep(1)  # Allow time for the server to start

        # Check if the server started successfully
        if rfc_process.poll() is None:
            print("RFC2217 server started successfully.\n")
        else:
            # Capture and display error output
            stdout, stderr = rfc_process.communicate()
            print("Failed to start RFC2217 server. Error output:\n")
            print(stderr.decode())
            sys.exit(1)  # Exit if the server couldn't start
    except Exception as e:
        print(f"Error starting RFC2217 server: {e}\n")
        sys.exit(1)

def run_power_shell_script():
    # This will run the PowerShell command without showing the window
    try:
        ps_command = [
            "powershell", "-WindowStyle", "Hidden", "-Command", 
            "python", "start_server.py"
        ]
        subprocess.Popen(ps_command, creationflags=subprocess.CREATE_NO_WINDOW)
    except Exception as e:
        print(f"Error starting PowerShell script: {e}")
        sys.exit(1)

def check_and_terminate_port(port):
    """Check if a port is in use and terminate the process using that port."""
    for proc in psutil.process_iter(attrs=['pid', 'name']):
        try:
            # Attempt to check for connections and see if the port is being used
            for conn in proc.net_connections(kind='inet'):
                if conn.laddr.port == port:  # Check if the local port matches
                    print(f"Port {port} is already in use by process {proc.info['name']} (PID: {proc.info['pid']}).")
                    print(f"Terminating process {proc.info['name']} (PID: {proc.info['pid']})...\n")
                    proc.terminate()  # Terminate the process using the port
                    proc.wait()  # Wait for the process to terminate
                    print(f"Process {proc.info['name']} (PID: {proc.info['pid']}) terminated successfully.\n")
                    return True
        except (psutil.NoSuchProcess, psutil.AccessDenied, psutil.ZombieProcess, AttributeError):
            # Handle processes without connections or processes that might have no access to certain details
            continue
    return False

def main():
    # Parse command-line arguments
    parser = argparse.ArgumentParser(description="Run Docker container and flash ESP32.")
    parser.add_argument('--flash', action='store_true', help="Flash the ESP32 after starting the server.")
    parser.add_argument('--start-container', action='store_true', help="Start the Docker container without flashing.")
    parser.add_argument('--non-interactive', action='store_true', help="Start the RFC2217 server and PowerShell script in the background.")
    args = parser.parse_args()

    # Check if port 4000 is in use, and terminate the process if necessary
    if check_and_terminate_port(4000):
        print("Port 4000 was in use and has been terminated. Now proceeding with the RFC2217 server...\n")
    else:
        print("Port 4000 is free.\n")

    # If --non-interactive is provided, run the PowerShell script in the background
    if args.non_interactive:
        run_power_shell_script()

    # List available serial ports
    ports = list_serial_ports()
    if not ports:
        print("No serial ports found.")
        if args.start_container:
            run_docker_command()
        else:
            print("Please connect the device and run the script again.")
            sys.exit(0)  # Exit if no serial ports are found and no container should be started
    
    else:
        print("Available serial ports:")
        for port in ports:
            print(f" - {port.device}: {port.description}")
        
        match_found = False
        for port in ports:
            if "Silicon Labs CP210x USB to UART Bridge" in port.description:
                print(f"Match found: {port.device} -> {port.description}")
                match_found = True
                # Run RFC2217 server before entering Docker container
                run_rfc2217_server(port.device)
                break
        
        if not match_found:
            if args.start_container:
                run_docker_command()
            else:
                print("No matching serial port found. Please connect the device and run the script again.")
                sys.exit(0)
        else:
            if args.flash:
                run_docker_command(is_flash=True)
            elif args.start_container:
                run_docker_command()

if __name__ == "__main__":
    main()

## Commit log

2024-10-27 Initial Embedded Directory Structure
    Initial upload for embedded software directory structure. Includes code relating to PIR sensor interfacing. Further commits should be made to feature branches.
2024-11-11 Added remote serial server for flashing esp32 from Docker container
2024-11-29 added entrypoint file edited CMake file to change main to src folder removed temporary folders for source code need to fix python script to build from local dockerfile instead of dockerhub
    [main.c, start_server.py]
2024-11-30 removed automatic task kill on port 4000 added wifi component, no functionality yet fixed main and cmakelists file
    [main.c]
2024-12-03 wifi functionality added in source code github actions updated to test docker image builds and upload esp32 build output
2025-01-06 moved kicad schematic to main branch
    [NFC.kicad_sch, PIR.kicad_sch, Programming.kicad_sch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]
2025-01-15 partition table setup
    [partition.csv]
2025-01-19 Working OTA updates - LED will change from blinking blue to blinking green after OTA update
2025-01-20 changed circuit for TFT display and added datasheets to directory
    [SCAN.kicad_sch]
2025-01-24 finished power management footprints and started layout
    [SCAN.kicad_pcb, SCAN.kicad_sch, USB_UART.kicad_sch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]
2025-01-24 footprint assignments and fixed PN532 breakout
    [SCAN.kicad_sch]
2025-01-30 firebase code and PCB layout
    [SCAN-B_Cu.gbr, SCAN-B_Mask.gbr, SCAN-B_Paste.gbr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]
2025-02-06 latest PCB
    [NFC.kicad_sch, SCAN.kicad_pcb, SCAN.kicad_sch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]
2025-02-10 created new mainboard PCB (original PCB minus the power control circuitry)
    [NFC.kicad_sch, PIR.kicad_sch, Programming.kicad_sch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]
2025-02-10 changed pin headers from vertical to horizontal and added connector for power inputs
    [SCAN_mainboard.kicad_pcb, SCAN_mainboard.kicad_sch]
2025-02-10 rerouting power pcb and fixed compile errors with Dre working on firebase firmware
    [SCAN.kicad_pcb]
2025-02-12 Added missing breakout connections to power PCB
    [SCAN_mainboard.kicad_pcb, SCAN_mainboard.kicad_sch]
2025-02-13 more hardware fixes
    [SCAN.kicad_pcb, SCAN.kicad_sch, USB_UART.kicad_sch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]
2025-02-13 more pcb edits
    [SCAN.kicad_pcb, USB_UART.kicad_sch]
2025-02-13 Updated schematic with CP2102N changes and other changes discussed in our 2/12/2025 meeting
    [SCAN_mainboard.kicad_sch, USB_UART.kicad_sch, auto_download.kicad_sch]
2025-02-13 Updated schematic errors as per Dre's instructions
    [SCAN_mainboard.kicad_pcb, SCAN_mainboard.kicad_sch, USB_UART.kicad_sch]
2025-02-14 swapped uart pins and added headers for power input muxing
2025-02-14 actually saved this time
    [SCAN_mainboard.kicad_sch]
2025-02-14 Layout progress for Dre changes
    [USB_UART.kicad_sch]
2025-02-14 Changed external connector to power PCB and reworked layout
    [SCAN_mainboard.kicad_pcb, SCAN_mainboard.kicad_sch]
